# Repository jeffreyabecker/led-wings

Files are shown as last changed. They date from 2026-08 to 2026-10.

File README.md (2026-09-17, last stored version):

# Wings

One-off LED-lit wing costume — off-the-shelf SK9822 strips cut into per-feather chunks, data
daisy-chained chunk-to-chunk, power fed from buck-module power-hubs, driven by a Pixelblaze.

## Build strategy

- **Off-the-shelf electrical system** — no custom PCBs for this build. SK9822 96 LED/m strips
  cut to per-feather LED counts; Pixelblaze V3 controller; buck-module + fuse power-hubs.
- Custom boards (KiCad 10 + `pcbnew` parameterized feathers) are deferred to "if we build
  more than one".

## Boards

- [Boards](boards/README.md) — the build plan: strip-chunk cut table, covert rows, controller,
  power hubs, settled COTS parts. **Source of truth for the electrical build.**

## Feather templates

- [Templates](mechanical/templates/) — **physical feather templating only**: outlines + geometry,
  the generator, and shape sourcing. No electronics content — lighting lives in
  [boards/lighting-and-boards.md](boards/lighting-and-boards.md).

## Mechanical

- [Mechanical](mechanical/) — physical wing structure: [structural](mechanical/structural/) frame

## Shared docs

- [Connector pinout](docs/connector-pinout.md) — pigtail wiring legend (PWR / DATA-IN / DATA-OUT wire pairs + colors)

## Investigations

- [Battery](investigations/battery/) — 12 V chemistry + sizing for 8 h @ 20 % mobility
- [Connectors](investigations/connectors/) — board-to-wire family options for the strip ends
  (pitch-split power/data, JLCPCB-assembled)

## Repository layout

- `boards/` — **electrical build**: strategy, feather lighting map, wiring legend, settled
  parts. All electronics information lives here (or in `docs/`).
- `mechanical/templates/` — **physical feather templating only**: outlines, geometry, generator,
  shape sourcing. No electronics/lighting content — that belongs in `boards/`.
- `mechanical/` — wing structure (frame, backplate, harness mounts).
- `docs/` — shared electrical references (connector pinout, pigtail crimp guide).
- `investigations/` — one-off research (battery, connectors, diffuser halo).

## Changing the plan

Update [boards/README.md](boards/README.md) — it is the single source of truth for the
electrical build.

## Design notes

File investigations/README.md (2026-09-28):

# Investigations

Non-board design investigations — architecture, part-selection, and cost questions that
don't yet have their own board folder. Each investigation keeps a `README.md` (scope +
decision context) plus one or more analysis notes.

| Investigation | Status | Question |
|---|---|---|
| [Battery](battery/) | investigation | Which 12 V battery (chemistry + size) powers 8 h @ 20 % for mobility? |
| [Connectors](connectors/) | investigation | Which 2-pin board-to-wire family (pitch/keying) for strip ends, JLCPCB-assembled? |
| [Diffuser halo](diffuser-halo/) | investigation | How to make a thin, directional, resin-free diffuser bent into a halo ring? |
| [Side-facing LED placement](side-facing-led-placement/) | investigation | Where do edge-lit strips sit (distance/angle/density) for ≤ 7 mm feathers with an opaque foam top? |
| [Wing bones](wing-bones/) | target | Bone-structure layout + backplate → build plan: [structural/wing-structure-plan.md](../structural/wing-structure-plan.md) |

## Conventions

- Status: `investigation` (in progress) · `target` (decided direction) · `recommended` · `rejected` · `superseded`.
- Cite the source for every spec or price; mark estimates `⚠️` vs confirmed `✅`.
- A recommendation here is an *input* to the [boards doc](../boards/README.md), not a locked
  decision. Locking decisions still happens there.

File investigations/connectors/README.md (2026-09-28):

# Board-to-Wire Connector Selection — Research

> **Status: proposal** — no connector family chosen yet. This supersedes the earlier
> JST-PNI wire-to-wire plan. Scope: **2-pin board-to-wire connectors for the strip ends**,
> **JLCPCB/LCSC-assembled** (part must be in the JLCPCB assembly library or available
> through LCSC for consigned/PCBA sourcing).

## Constraints (from project + user)

| # | Requirement | Source |
|---|---|---|
| 1 | **Small footprint / pitch** — strip is **10 mm wide**, chunk ends are tight | `boards/lighting-and-boards.md` |
| 2 | **Keyed vs unkeyed, or male/female split, so power ≠ data** | user requirement |
| 3 | **Board side must be JLCPCB-assembled** (SMT placement) | user requirement |
| 4 | Wire side is hand-crimped (or pre-made cable) | build reality |
| 5 | Current: power run ≤ ~1.4 A per chunk @100 %; data negligible | `boards/hub-board.md` §6 |
| 6 | Two separate 2-pin pairs per chunk end: **power** and **data** | `docs/connector-pinout.md` (legacy) |
| 7 | Wearable — must not back out under flex/vibration | `` |

## Key insight: how to stop mixing connectors

There are **three** independent mechanisms, and you want to use **two at once**:

1. **Pitch difference (best, mechanically enforced).** Power on one pitch, data on another.
   A data plug physically cannot enter a power receptacle. Zero label reading, zero mistakes.
2. **Keying / polarisation.** Same pitch, different key. Cheaper (one tool, one crimp die)
   but relies on the moulded key being distinct enough to feel.
3. **Gender / colour / position.** Weakest — colour is invisible in a wing at night; gender
   only stops the wrong *pairing* if the two families differ.

**Recommendation: use mechanism 1 (split by pitch) as the primary, and mechanism 3
(harness position discipline) as the secondary.** Details in the recommendation section.

## Candidate families

All parts below are standard, widely-stocked families that appear in the LCSC/JLCPCB
ecosystem (either directly as the JST original or as the ubiquitous pin-compatible clone).
Verify the exact LCSC C-number and JLCPCB library status before committing — see
§Verification.

### A. 1.0 mm pitch — JST SH class

| | |
|---|---|
| Board header (SMT, side entry) | `SM02B-SRSS-TB` |
| Board header (SMT, top entry) | `BM02B-SRSS-TB` |
| Wire housing | `SHR-02V-S-B` |
| Contact | `SSH-003T-P0.2-H` |
| **Pitch** | **1.0 mm** |
| **Current rating** | **1 A AC/DC (AWG #28)** |
| Voltage | 50 V |
| Wire | AWG #32–#28 (0.032–0.081 mm²) |
| Lock | Friction lock (no positive latch) |
| Mounting height | ~2.9 mm (side entry) |

**Verdict:** the smallest credible option. **1 A rating is marginal** — a power run at
1.2 A is already over the JST number. Fine for **data**, tight for power.

### B. 1.25 mm pitch — JST GH class

| | |
|---|---|
| Board header (SMT, side entry) | `SM02B-GHS-TB` |
| Wire housing | `GHR-02V-S` |
| Contact | `SSHL-002T-P0.2` |
| **Pitch** | **1.25 mm** |
| **Current rating** | **1 A AC/DC (AWG #28)** |
| Voltage | 50 V |
| Wire | AWG #30–#26 |
| Lock | **Friction lock + housing lock (positive latch)** |
| Mounting height | ~1.25 mm (very low) |

**Verdict:** as low-profile as SH but with a **proper latch** — a real win for a wearable.
Still 1 A, and the GH contact needs a **different crimp die** than SH (smaller).
GH is a strong "low-profile" pick but shares the 1 A ceiling.

### C. 1.5 mm pitch — JST ZH class

| | |
|---|---|
| Board header (SMT, side entry) | `SM02B-ZHS-TB` |
| Board header (SMT, top entry) | `BM02B-ZHS-TB` |
| Wire housing | `ZHR-2` |
| Contact | `SZH-002T-P0.5` |
| **Pitch** | **1.5 mm** |
| **Current rating** | **1 A AC/DC (AWG #26)** |
| Voltage | 50 V |
| Wire | AWG #32–#26 |
| Lock | Friction lock |
| Mounting height | ~3.5 mm |

**Verdict:** you already have `C145992` (ZH 4-pin) pulled into the library, so the
footprint and crimp tooling are known. Wider than SH/GH but the widest wire range.

### D. 2.0 mm pitch — JST PH class (already in use for hub taps)

| | |
|---|---|
| Board header (SMT, side entry) | `S2B-PH-SM4-TB` (aka `PH2.0-2PWB`, LCSC `C47647`) |
| Wire housing | `PHR-2` |
| Contact | `SPH-002T-P0.5S` |
| **Pitch** | **2.0 mm** |
| **Current rating** | **2 A AC/DC (AWG #24)** |
| Voltage | 100 V |
| Wire | AWG #32–#24 |
| Lock | Friction lock (with optional locking variant) |

**Verdict:** **the only family here rated for the power you actually need.** Already
specced for the hub taps, so the tooling, footprint and crimp die exist in the build.

### E. 2.0 mm pitch, keyed — JST PA class

| | |
|---|---|
| Board header (SMT, side entry) | `BM02B-PASS-TFT` |
| Wire housing | `PAR-02V` |
| Contact | `SPA-001T-P0.5` (or `-P0.5S`) |
| **Pitch** | **2.0 mm** |
| **Current rating** | **3 A AC/DC (AWG #22)** |
| Voltage | 250 V |
| Wire | AWG #28–#22 |
| Lock | **Positive lock (inner), panel lock** |
| Keying | **Yes — housing is polarised/keyed** |

**Verdict:** highest current in this survey (3 A), a real latch, and genuinely keyed.
Cost: 2.0 mm pitch is the largest footprint, and it needs its **own crimp die** — a third
die in the toolbox next to PH and the small-pitch family.
**Note:** the wire-to-wire sibling is the **PNI family** you originally picked — PA is its
wire-to-board partner, so this is the natural evolution of that plan.

### F. 2.0 mm, board-in (no header) — JST SJN class

| | |
|---|---|
| Board-in, side entry | `02P-SJN` |
| Contact | `SJN-001PT-0.9` |
| **Pitch** | **2.0 mm** |
| **Current rating** | **3 A AC/DC (AWG #22)** |
| Voltage | 250 V |
| Mounting | **Through-hole, side entry, 2.8 mm mounting height** |

**Verdict:** interesting because the housing **sits on the board** and you solder the
contacts straight through — no SMT header, no mating halves. But it is **through-hole**
(so *not* plain SMT assembly) and it is a board-in style, which means the wire exits the
board plane. Worth noting, probably not the pick here.

### G. 1.25 mm, unkeyed + latching alternatives (Molex PicoBlade / clones)

| | |
|---|---|
| Board header (SMT) | `53398-0271` (PicoBlade 1.25 mm, vertical) |
| Wire housing | `51021-0200` |
| **Pitch** | **1.25 mm** |
| **Current rating** | **1 A** |
| Lock | Friction lock |
| Note | PicoBlade clones (`MX1.25`) are **very** well stocked at LCSC, cheapest option |

**Verdict:** cheapest and best-stocked at LCSC, but **unkeyed** and 1 A — it fails the
"don't mix connectors" goal on its own. Use only if price dominates.

## Comparison

| Family | Pitch | Rating | Wire | Lock | Keyed | SMT | Die needed |
|---|---|---|---|---|---|---|---|
| **SH** | 1.0 mm | 1 A | #32–28 | friction | ✗ | ✓ | SH/1.0 |
| **GH** | 1.25 mm | 1 A | #30–26 | **latch** | ✗ | ✓ | GH/1.25 |
| **ZH** | 1.5 mm | 1 A | #32–26 | friction | ✗ | ✓ | ZH/1.5 |
| **PH** | 2.0 mm | **2 A** | #32–24 | friction | ✗ | ✓ | PH/2.0 *(have)* |
| **PA** | 2.0 mm | **3 A** | #28–22 | **latch** | **✓** | ✓ | PA/2.0 |
| **SJN** | 2.0 mm | 3 A | #28–22 | — | — | ✗ (THT) | — |
| **PicoBlade** | 1.25 mm | 1 A | #28–26 | friction | ✗ | ✓ | 1.25 |

## Recommendation

**Split by pitch — two families, two roles. This satisfies "small footprint" and
"can't mix them" simultaneously, with no reliance on colour or keys.**

| Role | Family | Board part | Rating | Why |
|---|---|---|---|---|
| **POWER** (hub tap ↔ chunk) | **PH, 2.0 mm** | `S2B-PH-SM4-TB` (`C47647`) | 2 A | Already in the BOM, tooling and footprint on hand; only family that clears the current; 2.0 mm is *wide on purpose* so it can never enter a data socket |
| **DATA** (chunk ↔ chunk) | **SH, 1.0 mm** *(or GH if you want the latch)* | `SM02B-SRSS-TB` | 1 A | Tiny, well-stocked, and 1.0 mm physically cannot mate with 2.0 mm PH |

Why this shape:

- **Physically enforced.** A 1.0 mm SH plug cannot enter a 2.0 mm PH receptacle and vice
  versa. Power/data mix-ups become impossible rather than merely unlikely.
- **Current-correct.** Data carries no current (regenerated SPI, negligible); 1 A is
  ample. Power gets the 2 A PH it already needs.
- **One new family only.** You already use PH. This adds exactly one small-pitch family
  (SH), not three.
- **Footprint budget.** 10 mm strip width fits a 2.0 mm power header plus a 1.0 mm data
  header side by side with room to spare.

**If you would rather have a positive latch on every connector** (strongly advised for a
wearable that flexes), swap the two rows:

| Role | Family | Board part | Note |
|---|---|---|---|
| POWER | **PA, 2.0 mm keyed** | `BM02B-PASS-TFT` | 3 A + latch + keyed — best electrical/safety pick |
| DATA | **GH, 1.25 mm latched** | `SM02B-GHS-TB` | latch in a tiny package |

This costs a third crimp die (PA) but gives a latch on both halves and 3 A on power.

**Fallback if price dominates:** PH (power) + PicoBlade/MX1.25 clone (data). Cheapest and
best-stocked, but the data side is unkeyed 1 A — acceptable *only* because the pitch
split already prevents mis-mating.

## Verification checklist (do before committing)

The LCSC/JLCPCB catalogue pages are JS-rendered and could not be scraped, so confirm each
of these in the JLCPCB parts library by hand:

1. **JLCPCB library status** — search the JST MPN *and* the generic name
   (e.g. `SM02B-SRSS-TB`, `SH 1.0 2P`, `S2B-PH-SM4-TB`, `PH2.0-2PWB`). JLCPCB stocks both
   JST originals and pin-compatible clones; confirm which, and whether it is
   **"Preferred"/"Standard"/"Extended"**.
2. **Record the LCSC C-number** for: board header, wire housing, and contact — all three,
   for each family. A missing housing/contact breaks the wire side.
3. **Assembled part vs basic part** — Extended parts may carry a per-order setup fee.
4. **Minimum order / reel** — SMT headers are tape-and-reel; confirm MOQ vs the ~300
   board-side connectors this build needs.
5. **Crimp die** — confirm a die exists for each contact series. The `SN-28B` style
   ratchet does **not** fit JST small-pitch contacts; budget one die per family.
6. **Current derating** — "1 A (AWG #28)" is at #28. If power runs at 1.2–1.4 A, stay on
   PH/PA (2–3 A), not SH/GH (1 A).
7. **Strip-side anchor** — confirm the SMT header + epoxy strain relief still fits the
   10 mm strip end (`boards/2020-leds/`).

## Open questions

- Does the strip end have room for a **2.0 mm header plus a 1.0 mm header**, or does the
  power tap stay on the hub side only?
- Is a **positive latch** a hard requirement, or is friction lock acceptable given the
  feathers will be potted/strain-relieved anyway?
- Do you want a **locking PH variant** (`S2B-PH-SM4-TB(LF)(SN)` has a friction lock; the
  `SM4` locking-latch variants exist) to get a latch without adding PA?
- Does JLCPCB assembly cover the **strip FPC** at all, or are the strip boards hand-built?
  This changes whether the board-side part must be in the JLC library.

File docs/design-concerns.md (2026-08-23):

# LED Lighting PCB — Design Concerns

> Project: Addressable LED lighting PCBs
> LED part: [SK9822-EC20](https://www.lcsc.com/product-detail/C2909059.html) (LCSC `C2909059`)
> Connectors: JST-PH style (input / output / power injection)

## Part summary

- **SK9822-EC20** — 5V addressable RGB LED with built-in driver IC.
- **Package:** 2020 SMD (2.0 × 2.0 mm), ~0.2 W per device.
- **Protocol:** 4-wire — `VCC`, `GND`, `DATA`, `CLK` (APA102-compatible). Separate clock and
  data lines, each regenerated on the device's `DO`/`CO` outputs.
- **Current draw:** ~40 mA per LED at full-brightness white (R+G+B all on).

References:
- [LCSC product page](https://www.lcsc.com/product-detail/C2909059.html)
- [SK9822-EC20 datasheet (Normand LED)](http://www.normandled.com/upload/202003/SK9822-EC20%20LED%20Datasheet.pdf)
- [SK9822-EC20 overview](https://www.normandled.com/Product/view/id/840.html)

---

## 1. Power delivery — the #1 problem (5V is unforgiving)

- Each LED draws ~0.2 W at 5V → **~40 mA at full-brightness white**. A 100-LED string is
  **4 A** — cannot be pushed through one thin trace or one connector pin.
- **Voltage drop:** at 5 V there is almost no headroom. Even 0.5 V drop = 10%, which shows up
  as pink/wrong colors (blue channel dies first) and flicker at the far end of the string.
  This is why power injection is planned — but the injection interval must be **calculated**,
  not guessed.
- **Copper weight / trace width:** a 1 oz, 10 mm-wide trace drops ~60 mV per meter per amp.
  At 4 A over a strip this adds up fast. Use 2 oz copper or wide pours; treat the power path
  as a bus, not a signal trace.
- **Ground is a bus too.** Return current is the same 4 A. Starving ground shifts the
  clock/data reference.

## 2. JST-PH connector limits (the critical constraint)

- **JST-PH is rated ~2 A per circuit** (typically mated with 24–28 AWG wire). One VCC pin +
  one GND pin = **2 A max through the connector** — roughly 50 SK9822 LEDs at full white, less
  with margin.
- For larger strings: **add more 2-pin injection points** (each ≤2 A) rather than a bigger
  connector.
- **Pinout discipline:** pick one canonical pinout and use it everywhere. A mismatched
  daisy-chain connector is the classic way to blow a whole string.
- **Polarity/reversal protection:** JST-PH is not keyed against swapping power polarity. Add
  series Schottky or P-MOSFET reverse-polarity protection and/or a fuse, plus unambiguous
  silkscreen marking.

## 3. Signal integrity (data + clock)

- Separate `CLK` + `DATA`, regenerated on each device's `DO`/`CO` outputs → far more robust
  than 1-wire WS2812. Still:
  - **Series resistor (33–100 Ω)** on DATA and CLK — lives on the controller board (external),
    damping the controller→first-board cable.
  - Keep clock and data paired and reasonably matched; avoid large loop areas.
  - Expect **5 V logic** on data/clock. Level shifting from the controller is handled
    **externally** — not a board-level concern.
- Long runs: `CLK` is the double-clock risk. A pull-down/termination on the last board's `CO`
  can help on very long daisy chains.

## 4. Decoupling / bypass caps

- **Bulk cap (100–470 µF)** at each power-injection point to absorb inrush/transients.
- **100 nF ceramic near each LED or every few LEDs** (0.1 µF per device ideal; one per 1–4
  LEDs in practice).
- Caps also suppress constant-current driver switching noise that couples back onto data lines.

## 5. Thermal

- 0.2 W/device is small, but a dense board at full white is a real heat load; the 2020 package
  has little thermal mass.
- Use **copper pours** on VCC/GND as heat spreaders; avoid tiny thermal reliefs that choke heat.
- For sustained full-white, derate current or add spacing/airflow — lifetime and color stability
  drop fast with junction temperature.

## 6. Layout & manufacturability

- The 2020 package has **fine pads and a specific center/thermal pad** — follow the datasheet
  footprint exactly. Pick-and-place + reflow, not hand-solder friendly at density.
- **Mark data direction on silkscreen** (`DI` vs `DO`) — SK9822 is directional; every board in
  the chain must be oriented consistently.
- Keep high-current power path separate from signal path; return `DO`/`CO` cleanly to the next
  connector without crossing the power bus.

## 7. Protections & robustness

- **Fuse** (or polyfuse) — on the controller/distribution board (one per strand).
- **ESD/TVS** — on the controller board; segments rely on the SK9822's internal ESD protection.
- Reverse-polarity protection as noted in §2 (stays per board).

---

## TL;DR

The two things most likely to kill the project:

1. **Current capacity vs. the 2 A JST-PH limit.**
2. **5 V voltage drop over the string.**

Followed by signal integrity on `CLK`/`DATA` and bypassing. Everything else is refinement.

## Open items / next steps

- [ ] Calculate LEDs per injection point and per PH connector at target brightness (trace width,
      copper weight).
- [x] Define canonical connector pinout — see [connector-pinout.md](connector-pinout.md).
- [x] Input/output both 4-pin for off-the-shelf cables; direction marked by silkscreen — see [connector-pinout.md](connector-pinout.md).
- [x] Source connector part numbers (Boomele/JST-PH on LCSC) — see [selected-parts.md](selected-parts.md).
- [ ] Schematic symbol/footprint spec (connectors + SK9822-EC20).

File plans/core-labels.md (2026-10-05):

# Plan: label the geometry core

**Status:** proposed, not executed.
**Scope:** add `inkscape:label` attributes to the elements of
`templates/aggregate.svg` so the core is navigable in Inkscape's Objects and XML
panels. **No ids are renamed** — every existing `id` stays byte-identical, so the
sheets masters' `../aggregate.svg#<id>` hrefs keep resolving and nothing needs
rewriting.

Verified against the working tree after the reorg landed (`templates/aggregate.svg`,
769 lines, 129 elements, 134 ids, **0 duplicate ids**, **0 elements without an id**).
The reorg is mid-flight in the worktree: the two sheets documents and the core are
currently not well-formed XML, which is why the mechanics below are stated as
"by hand in Inkscape" rather than as a script step.

## 1. Why labels at all

Inkscape's Objects panel and the XML editor's element list show `inkscape:label`
when an element has one, and the raw `id` otherwise. The core's ids are either terse
by design (`P1-outline`) or Inkscape-generated noise (`path5-8`, `path13-2`,
`path55`-style dividers), so a maintainer opening the file today reads a list of
`path1 … path66` with no way to tell a divider from a wing profile. A label is the
only fix that does not rename anything, and renaming is exactly what we are avoiding
so the sheets masters keep working.

Labels are **maintainer metadata, not product data**: `inkscape:` is a
non-standard namespace, so the flattener strips every label on the way out. A
shipped CAM file must not carry them.

## 2. What gets a label

Counted from the current file, by class:

| count | element | role |
|---|---|---|
| 28 | `<path class="outline">` in a `<g class="feather">` | the catalog parts |
| 28 | `<path class="divider">` | the dividers between the feathers of one family |
| 8 | `<g class="align">` + 8 `<path class="outline">` inside them | the diagnostic overlays |
| 8 | `<path class="guide">` | the `*-topline` guides in `assembly-template` |
| 1 | `<path class="outline" id="path5-8">` in `<g id="full-outline">` | whole-wing profile |
| 1 | `<path class="outline" id="upper-outline">` in `<g id="assembly-template">` | upper cover of the assembly |
| 8 | `<g class="family …">` | the family groups |
| 6 | calibration `<line>`/`<text>` | the scale reference |
| 3 | misc `<g>` wrappers (`full-outline`, `align`, `assembly-template`, `calibration`) | containers |

That is ~91 elements. The eight `<g class="family …">` groups are worth doing
because the Objects panel nests by group, so the family is the first thing a
maintainer sees and the label is what names it.

## 3. Label text

One rule: **the label names the element in the maintainer's vocabulary, and repeats
the id only when the id is the identity a person would search for.** No id is ever
encoded into a label that does not already contain it.

| element | label | why |
|---|---|---|
| `<g class="feather" id="P1">` | `P1 right feather` | the id is the part identity |
| `<path class="outline" id="P1-outline">` | `P1 outline` | confirms which path in the group is the cut profile |
| `<g class="family p">` | `P family` | family letter + kind |
| `<path class="divider" id="path1">` | `P divider` | the generated id says nothing; the role does |
| `<g class="align" id="P-align">` | `P align overlay` | distinguishes the overlay from the family |
| `<path class="outline" id="path8-1">` | `P align outline` | the overlay's outer boundary |
| `<path class="guide" id="P-topline">` | `P topline guide` | assembly alignment line |
| `<path id="path5-8">` | `wing outline` | whole-wing profile; **needs your confirmation** |
| `<path id="upper-outline">` | `upper cover outline` | **needs your confirmation** |
| `<line id="calibration-centerline">` | `calibration centreline` | — |
| `<line id="calibratin-zero-line">` | `calibration zero line` | id keeps its typo; the label does not |
| `<line id="metric-50mm-line">` | `calibration 50 mm` | — |
| `<line id="us-2in-line">` | `calibration 2 in` | — |
| `<text id="metric-50mm-label">` | `50 mm text` | — |
| `<text id="us-2in-label">` | `2 in text` | — |

Two open questions in that table, both because I am inferring from id, path length
and parent transform rather than from knowing what the path draws:

- `path5-8`, the single path inside `<g id="full-outline">`, whose parent carries
  `translate(-1317.2834,-272.68523)`, and whose `d` is the longest in the file
  (~2300 chars). I read it as an exported whole-wing profile.
- `upper-outline`, the single `<path class="outline">` in `assembly-template`,
  sitting above eight `*-topline` guides. It is referenced nowhere else in the tree,
  so what it depicts is not recoverable from the file.

## 4. Label uniqueness

The flattener's manifest keys rows on a name, so labels must be unique even though
Inkscape does not enforce that. Two families of near-collision, both already avoided
by the table above:

- **The overlay vs. its family.** `<g id="P-align">` is `P align overlay`, and the
  family group `<g class="family p">` is `P family` — the letter alone would collide.
- **The overlay's outline vs. the part outline.** `P align outline` vs `P outline`.

Verification must therefore include a duplicate-label check (§6), not just a
coverage check.

## 5. Mechanics

Do it **by hand in Inkscape**, not by script:

1. Open `templates/aggregate.svg`. Saving from Inkscape repairs the current
   well-formedness breakage as a side effect, which a scripted edit cannot do (a
   script would have to parse the broken file first).
2. Select an element, open Object Properties (`Ctrl+Shift+O`), type the label. The
   Objects panel (`Ctrl+Shift+L`) shows the same labels and is the fastest way to
   walk a family and its dividers in order.
3. For the divider paths and the two unknown outlines, the canvas is the only
   reliable way to find them: their generated ids are unique, so `Edit → Find`
   (or the XML editor's element list) can select by id when the drawing position is
   ambiguous.
4. Save with Inkscape's default SVG 1.1 output.

No script, no `id` attribute is touched, and no other file changes. Git will show a
single-file diff of added label attributes (plus whatever Inkscape normalises on
save, which is why this should land as its own commit).

## 6. Verification

- Every element in §2 carries a non-empty `inkscape:label`: count labels against the
  element census (28 parts, 28 dividers, 8 align groups, 8 align outlines, 8 guides,
  8 families, 6 calibration, the two unknowns, the wrappers).
- **No duplicate labels** across the whole file.
- **No `id` changed**: `git diff` shows only added `inkscape:label` attributes on
  those lines, and the id set before and after is identical.
- `templates/feathers/sheets.svg` and `templates/alignment/sheets.svg` still resolve
  their `../aggregate.svg#<id>` hrefs — they were never edited, so this is a check
  that the "no renames" promise held, not a repair.
- Open the core in Inkscape's Objects panel: families nest, and every leaf reads as
  a name rather than `path42`.

## 7. Out of scope

- Renaming any id (deliberately deferred; it would break the two sheets masters).
- Labels in the shipped CAM output — the flattener removes the `inkscape:` namespace
  entirely.
- The current well-formedness breakage in the three SVGs, beyond Inkscape repairing
  the core on save. If the sheets masters are still malformed when this lands, that
  is a separate fix.
- A convention entry in `templates/AGENTS.md` recording "new core geometry gets a
  label, and label text follows §3" — worth adding, but it belongs with whatever
  edits that file next.

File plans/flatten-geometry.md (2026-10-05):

# Plan: flatten a work file into CAM geometry (`flatten_geometry.py`)

**Status:** proposed, not executed.
**Scope:** a new stdlib-only Python script that reads a *work file* — a document
that composes geometry out of a geometry core by `<use>`, orients it, and selects a
subset — and writes raw, flat, bed-ignorant geometry for CAM software to position
inside a machine. It does not change `tile_sheets.py`, `plans/templates-reorg.md`'s
print pipeline, or the geometry core's ids.

Settled in review (this is the design driver, not an inference):

- the input is a **new kind of document**, not the tiler's print output and not the
  geometry core: it carries `<use>` references into the core, plus rotation,
  reorientation and subset selection;
- the output is **ignorant of the CAM bed** — no tiling, no paper, no pages, no
  registration marks, no bed frame. The CAM software positions the work under the
  user's own target conditions, so the flattener's job is *simplify*, not *lay out*.

Consequence: `tile_sheets.py` is not in this pipeline at all. Tiling is a printing
concern (page-sized stock, overlap bands, join marks) and the bed is a CAM concern;
each is somebody else's stage. The flattener only resolves and simplifies.

## Decisions this plan encodes

| decision | choice |
|---|---|
| script name | `flatten_geometry.py` |
| input | a work file: `<content>-work.svg` (see §2 — the one naming question still open) |
| geometry core | referenced by the work file, never opened as the top-level input |
| output location | `templates/cam/` (as directed) |
| output names | `templates/cam/<work>-<subset>.svg`, one file per selected work |
| output frame | **no bed frame**; units declared as mm, origin owned by the work file |
| coordinate system | absolute millimetres, **every transform baked into path data** |
| shapes | `rect`/`circle`/`ellipse`/`line`/`polyline`/`polygon` → `<path>` |
| emitted geometry | centreline cut paths only; labels, bounds, guides, reg marks dropped |
| CSS | all styling stripped; geometry is `fill:none`, `stroke:none`; kerf offered as an optional non-authoritative attribute and in the manifest |
| manifest | `templates/cam/index.tsv`, one row per emitted path plus a census of what was dropped |

## 1. What the script is called

**`flatten_geometry.py`**, at the repo root beside `tile_sheets.py` (or in
`templates/` if `plans/templates-reorg.md` moves the tools there). `flatten` is the
SVG term for resolving `<use>` into copies; `geometry` names what survives — this is
not a general-purpose flattener, because labels, bounds, guides and marks are
losses it makes on purpose.

Rejected: `flatten_for_cam.py` (names the audience, not the transform),
`resolve_use.py` (describes only the first of the three things it does),
`flatten.py` (too generic beside `tile_sheets.py` / `inline_css.py`).

CLI, mirroring `tile_sheets.py`'s conventions (`USAGE` string, positional input,
explicit `--out`, `--whatif`, stdlib only, no argparse):

```
python flatten_geometry.py <content>-work.svg --out templates/cam/<work>-<subset>.svg
                            [--subset <group-id>]... [--all-subsets]
                            [--geometry <core.svg>] [--ref-dir <dir>]...
                            [--kerf] [--include-reference] [--include-marks]
                            [--keep-groups] [--check] [--whatif]
```

- `--subset` takes a group id inside the work file; repeatable. Without it, the whole
  work file is flattened as one work (the file's own selection stands).
- `--out` is required and is the file when exactly one work is emitted, the directory
  when several are (`--all-subsets`); the stem is derived per subset. Same rule as
  the tiler: no inferred output location, because a relative path written into a
  file is the failure mode this whole pipeline exists to delete.
- `--geometry` pre-seeds the core document so a work file copied away from its tree
  still resolves; `--ref-dir` adds search paths.
- `--check` re-flattens and compares against the committed output without writing.
- `--whatif` prints the resolved chain per path, the subset census, and the paths it
  would write.

## 2. What the input files are named

Two documents, two roles:

| role | name | contents |
|---|---|---|
| geometry core | `aggregate.svg` (reorg plan's name for today's `templates/feathers-elongated.svg`) | the 74 `<path>`s, ids `A1-outline` … `LC-All-outline`; 0 `<use>` |
| work file | `templates/<content>/<content>-work.svg` | `<use>` into the core, transforms, and the subset groups |

The work file is the composition layer: *this* content, rotated and reoriented like
this, using *these* parts. Today that role is played by
`templates/sheets-home-feathers.svg` and `templates/sheets-home-alignment.svg` —
43 and 18 `<use>` respectively, including the 14 self-referencing mirror clones
(`#sheet-P1-half` through `matrix(-1,0,0,1,210,0)`). Those files are exactly the
"new type of input" the brief describes; the plan's assumption is that they get the
`<content>-work.svg` name rather than a new sibling being invented beside them.

> **Open question, flagged not decided:** whether the work file *is* the existing
> sheets document renamed, or a third layer above it. Everything else in this plan is
> independent of the answer — the flattener takes one work file and a core, whatever
> they are called — but §3's output names are derived from the work file's stem, so
> the name has to be settled before the first run.

Naming grammar, so the pipeline reads out loud:

```
aggregate.svg             the geometry core (ids, no references)
<content>-work.svg        selection + orientation of core geometry
templates/cam/<stem>.svg  flattened, bed-ignorant output
```

No output name contains a `templates/` path, a paper token, a page number, or an
`id` from the core, so the whole tree can be renamed without touching the script.

## 3. What the output files are called

`templates/cam/`, as directed — below the tree that owns the sources, and outside
`targets/` because the CAM output is neither a print target nor paper-specific:

```
templates/cam/
  index.tsv                            manifest: every emitted path + the drop census
  README.md                            what regenerates this; nothing here is hand-edited
  feathers-work.svg                    whole work file, one work
  feathers-work-P1.svg                 --subset P1 (if subsets are emitted separately)
  alignment-work.svg
```

- The stem is the work file's stem, so source and output pair up by name
  (`feathers-work.svg` → `templates/cam/feathers-work.svg`).
- `--subset <group-id>` appends the subset token: one file per selected work, because
  a subset is a cutting job and mixing two jobs in one file is how the wrong profile
  gets cut.
- The **manifest** `templates/cam/index.tsv` is the thing that makes the tree
  auditable (tab-separated, one row per emitted path):

  | column | meaning |
  |---|---|
  | `work`, `subset`, `group` | source work file stem, subset id, the `id` of the group holding the path |
  | `role` | `cut` · `reference` · `mark` |
  | `path_id` | the emitted path's id |
  | `min_x`,`min_y`,`max_x`,`max_y` | tight bounds, mm, in output coordinates |
  | `kerf_mm` | the source stroke width, when `--kerf`; empty otherwise |
  | `src` | the resolution chain: `feathers-work.svg#P1R-use → aggregate.svg#P1-outline` |
  | `dup_of` | first entry that emitted identical geometry (mirror / duplicate detection) |

- `index.tsv` also carries a **drop census**: every dropped class with its count
  (`.label`, `.title`, `.note`, `.sheet-bounds`, `.reg*`, `.crop`, `.overlap`,
  `.guide`, `.divider`, `.cal*`, `.align`) and every subset that produced zero cut
  paths **with the reason**. In this tree that matters immediately: the cover and
  every `sheet-Alignment-*` group is layout and guide geometry, not parts, so those
  subsets are legitimately empty and must say so rather than look like a bug.

## 4. How the geometry is placed and organized

A work file is a cutting job, so the output is one document = one job, with no
notion of a bed, page, paper or machine:

1. **No frame is invented.** The flattener must not emit a `viewBox` sized to a
   sheet, a page or a bed — that is the bed coupling the brief rejects, and it would
   smuggle a placement decision into a file whose whole point is that placement is
   the CAM software's job. To make units unambiguous the root declares
   `viewBox="0 0 W H"` spanning the emitted geometry's tight bounds and
   `width="Wmm" height="Hmm"`, i.e. 1 user unit = 1 mm *by construction* — the frame
   is derived from the geometry, never the geometry fitted to a frame.
2. **No transforms survive.** The work file's rotations (e.g. `rotate(-4.0415212,
   -2276.4602,237.48561)` on `P1R-use`) and the mirror's `matrix(-1,0,0,1,210,0)`,
   the enclosing `translate` on `#sheets`, and the core's own
   `translate(-1317.2834,-272.68523)` on `full-outline` are all multiplied into path
   coordinates. Geometry gets `transform=None`, so an importer that ignored
   `transform` entirely would still be correct. `--keep-groups` preserves nesting
   with its transforms for eyeballing only.
3. **Path conversion.** `rect`, `circle`, `ellipse`, `line`, `polyline`, `polygon`
   become `<path>` (circles as two 180° arcs, `rx`/`ry` as corner arcs). No `<use>`,
   `<symbol>`, `<defs>`, `<clipPath>`, `<text>`, `<image>`, `style=`, or `class=`
   remains — the output has no dependency any consumer could drop.
4. **Groups keyed on source identity, never on position.** One `<g>` per subset and
   one per part, children in work-file document order:

   ```xml
   <g id="work" data-work="feathers-work" data-units="mm">
     <g id="subset-P1" data-subset="P1">
       <g id="part-P1R" data-part="P1" data-side="right" data-role="cut">
         <path id="P1-outline"
               d="…"
               data-src="feathers-work.svg#P1R-use → aggregate.svg#P1-outline"/>
       </g>
       <g id="part-P1L" data-part="P1" data-side="left" data-role="cut" data-mirror="of:part-P1R">
         <path id="P1-outline-mirror" d="…"/>
       </g>
     </g>
   </g>
   ```

   Ids come from the resolution chain (`part-P1R`, `P1-outline-mirror`), not from an
   array index, so adding a part does not renumber the others — the masters already
   name their groups this way (`sheet-P1-half`, `sheet-P1-labels`). The mirror stays
   explicit: it is a real geometric distinction (a flipped part is not a duplicate),
   and CAM needs to know a path is the reflected copy.
5. **What is kept by default** — the subset that represents material to be cut:

   | source class | emitted as | default |
   |---|---|---|
   | `.outline` inside a `class="feather"` group | `data-role="cut"` | **kept** |
   | `.outline` inside `.align` (the `*-align` / `A-align` overlay) | `data-role="reference"` | dropped (`--include-reference`) |
   | `.guide`, `.divider`, `.arrow` | `data-role="reference"` | dropped (`--include-reference`) |
   | `.reg`, `.reg-hole`, `.reg-axis`, `.reg-key` | `data-role="registration"` | dropped (`--include-marks`; these are print/assembly registration, not bed registration) |
   | `.cal`, `.minor`, `.major`, `.num`, `.caltext` | `data-role="mark"` | dropped (`--include-marks`) |
   | `.label`, `.title`, `.note` (`<text>`) | never emitted | dropped always — a cutter cannot cut text |
   | `.sheet-bounds`, background rects, `.crop`, `.overlap` | never emitted | dropped always |

   The drops are the "simplify for CAM" half of the brief: the operator wants cut
   profiles, and every other element is a printing or proofing aid. The `--include-*`
   flags exist so the same resolver can emit a reference or alignment program
   without a second tool.
6. **Ordering is the work file's, and it is preserved.** Nesting order, sibling
   order and each rotation land in the output exactly as the work file composed
   them; the flattener never sorts, optimises, or re-nests. If the work file says
   "P1 is rotated 4° anti-clockwise to fit the stock," that rotation is baked and the
   output records it in `data-src`, so the CAM operator inherits the decision instead
   of being asked to reproduce it.

## 5. What CSS is emitted

**None.** No `<style>` element, no `class` attribute, no presentation attribute on
the document — the CAM consumer's CSS support is unknown and unknowable, and a
stylesheet that *is* honoured produces a different file from the one that is not.
Styling is not geometry, so nothing about the geometry's *position* depends on it:

1. **Geometry carries only geometry.** Every emitted shape gets `fill="none"` and
   `stroke="none"` so no downstream default (a viewer's black fill, a CAM import's
   fill-to-path) can turn a cut profile into a filled region. No `stroke-width`,
   `stroke-dasharray`, `opacity`, colour or `font-*` survives — the source's
   `.outline { stroke-dasharray: 2.5, 2.5 }` (present in every master today) and the
   `.overlap { stroke-dasharray: 2 2 }` rule both disappear with the stylesheet, which
   removes by construction the class of bug the reorg plan calls out as live dashed
   cut paths.
2. **Kerf is data, not style, and it is opt-in.** `--kerf` adds
   `data-kerf-mm="0.5"` (the stroke width the source cascade resolved to) to each cut
   path and fills the manifest's `kerf_mm` column. It is deliberately *not* a
   `stroke-width`: a CAM file must not let a renderer's stroke be mistaken for a
   toolpath offset, and cutter compensation is the CAM software's decision. With the
   flag off, the manifest still records the resolved value, so a wrong kerf is visible
   before cutting without putting it in the geometry.
3. **Widths are millimetres and stated once.** The unitless source widths are only
   meaningful against an mm viewBox; §4.1 makes that true by construction and the
   manifest restates it, so `0.5` cannot be silently read as 0.5 px.
4. **Provenance is a comment, not styling** (same shape as the tiler's stamp):

   ```
   <!-- flattened by flatten_geometry.py: work=<path> sha256=<8> core=<path> sha256=<8>
        subsets=1 cut_paths=28 mirrors=14 dropped=labels:56,bounds:15,reg:105,guide:8
        css=none kerf=0.5 -->
   ```

   The source hashes are what make a flattened file traceable to the exact revision
   that produced it — the property the `<use>` documents get for free by pointing at
   their sources, and the reason a stripped file needs a stamp.

## 6. Verification

- No `<use>`, `<symbol>`, `<defs>`, `<clipPath>`, `<text>`, `transform=`, `url(#…)`,
  `href=`, `class=`, `style=`, `<style>` or `stroke-width` survives in any
  `templates/cam/*.svg`. Grep the emitted tree: this is the check that catches the
  no-op-that-looks-like-success failure mode, so it is a hard gate.
- Feathers work file: 28 distinct cut profiles per the catalog (14 parts × right/left),
  the 14 mirrored paths are reflections about their part's axis and are paired in the
  manifest by `dup_of`, and no two entries share identical `d` unless genuinely
  congruent parts do.
- Bounds: every emitted path's bounds lie inside the root `viewBox`, and the viewBox
  is the tight union of them.
- `index.tsv` lists the cover and every `Alignment-*` subset with `cut_paths=0` and a
  reason, and the drop census counts match the source (`labels:56`, `bounds:15`,
  `reg:105` for the current feathers sheets — measured, see the working tree).
- Render one flattened output at 1 mm/unit and overlay the source's equivalent region
  (Inkscape CLI `--export-type=png`, `--export-dpi`): the cut ink is congruent. A
  mismatch means a transform was multiplied in the wrong order (outermost first).
- A hand-edit to a baked `d` is reported by `--check` (try it once, revert).
- Re-flattening unchanged inputs is byte-identical, which is what lets the tree be
  regenerated on every master edit.

## 7. Risks and notes

- **The input name is the open decision** (§2). Everything else here is independent
  of it, but `templates/cam/` output stems derive from the work file's stem.
- **`templates/` is moving.** `plans/templates-reorg.md` renames the core to
  `aggregate.svg` and relocates every document. The naming grammar above is chosen to
  survive it: no output name encodes a `templates/` path, a paper token, or a sheet
  id.
- **The core is referenced by id, so a core rename breaks the work files**, not the
  flattener. The flattener fails loudly on an unresolvable href, naming the href and
  the file it looked in — the deep-relative-path silent failure is the known incident
  this repo keeps re-learning.
- **Nothing about cutting offsets.** With `stroke="none"` and no width, the output is
  centrelines; a CAM post that needs an offset outline does it downstream. That is
  the intended division of labour, and the reason `--kerf` is advisory.
- **Commit the output tree**, like `templates/targets/` per the reorg plan, so an
  operator can check out the repo and get the exact geometry that was cut.

## 8. Out of scope

- Tiling, pagination, overlap bands, join marks, paper sizes, registration marks —
  the printing pipeline's job (`tile_sheets.py`), and explicitly not the flattener's.
- Bed fitting, nesting, work offsets and toolpath ordering — the CAM software's job,
  which is the point of a bed-ignorant output.
- Stroke-to-path / offset outlines, DXF, HPGL, G-code, and any machine post.
- Any change to the geometry core's ids or the work files' geometry.

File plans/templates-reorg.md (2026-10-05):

# Plan: reorganize `templates/`

**Status:** tiler prerequisite **done**; the reorg itself is proposed, not executed.

- The `tile_sheets.py` behaviour changes that the re-tile depends on have landed (commit
  `e568aed`) and are recorded under [Tiler state](#tiler-state-landed) below, which is the
  residual of the former `plans/tile-sheets-changes.md`. Nothing else from that plan remains.
- What is left is everything below: the directory structure, file renames, reference rewrites, the
  CSS consolidation (one source per audience, generated into every document), and the folder docs
  that make the layout self-explanatory. No geometry or content changes.

Facts below were re-verified against the working tree at the time of writing.

## Decisions this plan encodes

| decision | choice |
|---|---|
| sheet masters vs targets | masters are target-agnostic, so they live **above** `targets/` |
| layout shape | `templates/<content>/sheets.svg` + `templates/targets/<target>/<content>/print-<paper>.svg` |
| print document references | keep thin `<use>` references (no inlining), accepting parent-directory hrefs |
| stylesheet | one source per audience under `templates/css/`, **generated into every SVG** at build time; nothing referenced at runtime |
| paper naming | `print-letter.svg`, `print-a4.svg` — the `--paper` token, so flag value and filename agree |
| `aggregate.svg` | the geometry master that sheets reference by id (today's `feathers-elongated.svg`) |
| PDFs | rendered from the print documents, parked at the target level |

## Tiler state (landed)

`tile_sheets.py` at the repo root already speaks the grammar this plan assumes, so the re-tile in
[step 4](#steps) needs no code change. Verified against the current masters:

| behaviour | state |
|---|---|
| sheet reference | relative to the output directory (`os.path.relpath` + `os.sep` → `/`), via `rel_href()` |
| output | `--out` required and its directory created; `--whatif` reports path, resolved href and output size |
| `sodipodi:docname` | the real output basename (`doc_name=os.path.basename(out_path)`) |
| provenance | one XML comment before `<svg>`: `tiled by tile_sheets.py: source=… paper=… trim=… safe=… overlap=… gap=… pages=… orientation=per-sheet` |
| shared defs | rendered by `emit_multipage_svg(shared_defs=…)`; no post-hoc `replace()` of the `<defs>` marker, so the silent no-op is gone |
| stylesheet | carried over from the master and gated: `require_style_rules()` fails unless the carried CSS plus `JOIN_CSS` defines `.join-line`, `.join-bar`, `.overlap`, `.note`. The old unconditional `CSS2` append is gone |
| CLI | `--paper <name>` required (or `--size WxH`), `--margin`/`--safe`, `--overlap`/`--gap`, `--list-papers`; sheet discovery is a class **token** test, so `sheet-bounds` and friends cannot match |

Measured with the current masters (letter, default overlap 12 / gap 10):

```
templates/sheets-home-feathers.svg    -> 28 pages from 15 sheets (13 tiled, 2 single-page)
templates/sheets-home-alignment.svg   -> 19 pages from 12 sheets (7 tiled, 5 single-page)
```

Both documents were regenerated and inspected: page counts 28 / 19, `class="…"` usage limited to
`join-line`, `join-bar`, `overlap`, `note`, two hoisted clip defs (`clip`, `clip-shared-2`), and a
provenance comment matching the parameters. These are the reference numbers for the post-reorg
re-tile; the regenerated files were not kept (see [step 4](#steps)).

## Target layout

```
templates/
  README.md                       naming grammar, pipeline, regeneration commands
  AGENTS.md                       folder rules (masters vs generated, machining model, registration)
  aggregate.svg                   geometry master, id-referenced by <use>
  css/
    geometry.css                  part, guide and mark presentation
    sheets.css                    sheet, label and registration presentation
  inline_css.py                   writes each master's <style> from css/; --check reports drift
  tile_sheets.py                  the tiler (moved here as drawn)
  feathers/
    sheets.svg                    sheet layouts, mm, registration + mirror pattern
    AGENTS.md
  alignment/
    sheets.svg
    AGENTS.md
  targets/
    AGENTS.md                     everything below here is generated
    home/                         US/ISO home-printer paper
      AGENTS.md                   canonical commands + parameter sets per paper
      feathers/
        print-letter.svg
        print-a4.svg
      alignment/
        print-letter.svg
      feathers-letter.pdf
      alignment-letter.pdf
```

The `multipage` moniker is retired: the stage word is `print`, and the only thing that varies in
the name is the paper.

## File mapping

| now | after | notes |
|---|---|---|
| `templates/feathers-elongated.svg` | `templates/aggregate.svg` | geometry master, 250×700 mm, own stylesheet, 0 `<use>` |
| `templates/sheets-home-feathers.svg` | `templates/feathers/sheets.svg` | 15 sheets; 29 external hrefs + 14 internal mirror `<use>` |
| `templates/sheets-home-alignment.svg` | `templates/alignment/sheets.svg` | 12 sheets; 18 external hrefs |
| `templates/sheets-home-feathers-multipage.svg` | `templates/targets/home/feathers/print-letter.svg` | 28 pages; 28 external refs — **regenerate**, the file was deleted in `e568aed` |
| `templates/sheets-home-alignment-multipage.svg` | `templates/targets/home/alignment/print-letter.svg` | 19 pages; 19 external refs — **regenerate** |
| — | `templates/targets/home/feathers/print-a4.svg` | new output, same master, A4 paper |
| — | `templates/targets/home/feathers-letter.pdf` | render of `feathers/print-letter.svg` |
| — | `templates/targets/home/alignment-letter.pdf` | render of `alignment/print-letter.svg` |
| — | `templates/css/geometry.css`, `templates/css/sheets.css` | new: the stylesheet sources |
| — | `templates/inline_css.py` | new: generates each master's `<style>` from `css/` |
| `tile_sheets.py` (repo root) | `templates/tile_sheets.py` | move only; behaviour work has landed |
| `templates/print/` | *deleted* | empty directory, absorbed by `targets/` |
| `templates/sheets-home-print.pdf` | *deleted* | orphan: its source SVG was removed at the split |
| `templates/feathers-letter-landscape.pdf` | *deleted* | orphan: `feathers-aggregate.svg` no longer exists |

The two multipage SVGs are the one place this plan differs from a pure rename: they were deleted in
the "cleaning up svgs and tiling" commit and are untracked-generated now, so there is no history to
carry. Generate them at their new paths and let the first commit record them as additions.

## Reference rewrites

Only two kinds, both mechanical:

1. **Masters → geometry master.** Every external `<use>` in both `sheets.svg` files changes
   `feathers-elongated.svg#<id>` to `../aggregate.svg#<id>`:
   - `feathers/sheets.svg`: 29 occurrences (28 outline symbols + `calibration`)
   - `alignment/sheets.svg`: 18 occurrences (8 `*-align` symbols + `assembly-template`)
2. **Print documents → masters.** Regenerated, never hand-edited. The tiler emits
   `../../../feathers/sheets.svg#sheet-P1` (three levels: `feathers` → `home` → `targets` →
   `templates`). 28 references for feathers, 19 for alignment.

Untouched by any of this: all element ids, sheet ids, `inkscape:current-layer`, `data-sort-order`,
the registration geometry, and the mirror `<use href="#sheet-*-half">` references. The `<style>`
bodies are rewritten, but their rules keep their meaning apart from the fixes listed below.

## CSS consolidation

The presentation exists in three hand-maintained copies that have already drifted — `aggregate.svg`
1,549 chars / 19 rule blocks, `feathers/sheets.svg` 2,836 / 39, `alignment/sheets.svg` 2,668 / 35.
The tiler no longer adds a fourth: it carries the master's stylesheet over unchanged and only adds
the two rules for its own join marks (`JOIN_CSS`).

**Shape:** one source per audience, generated into every document at build time. Nothing is
referenced at runtime.

| source | contents | generated into |
|---|---|---|
| `css/geometry.css` | `.outline`, `.guide`, `.arrow`, `.divider`, `.mark`, family fills | `aggregate.svg`, both `sheets.svg` |
| `css/sheets.css` | `.label`, `.title`, `.note`, `.sheet-bounds`, `.crop`, `.overlap`, `.reg*` | both `sheets.svg` |

Each document therefore carries the rules it needs for its own rendering, so a `sheets.svg` styles
its own clones of `aggregate.svg` geometry without depending on the geometry master being reachable
*as a stylesheet*.

- **Generator**: `templates/inline_css.py` rewrites each master's `<style>` body from the sources;
  `--check` fails when a document's rules no longer match the source. Compare rules
  (selector → declarations, order-insensitive), not bytes: Inkscape normalises CSS syntax when it
  re-saves a file, so a byte comparison would report drift that isn't.
- **Which source each document gets**: `aggregate.svg` gets `geometry.css` only — it renders
  geometry, not sheets — and both `sheets.svg` files get `geometry.css` + `sheets.css`. A
  `sheets.svg` must keep the geometry rules because it clones `aggregate.svg` content, and the
  tiler carries that same style text into every print document.
- **Why inline instead of `@import`**: a stylesheet reference is a runtime dependency with a silent
  failure mode. Any consumer that is not Inkscape — a CAM tool, a browser, a PDF flattener — may drop
  it, and cut paths would quietly lose their stroke. Inlining keeps every document self-contained.
- **Measured rather than assumed** (Inkscape 1.4, the version the files declare; probes left in
  `.tmp/css-probe/`): inline `<style>` works; `@import url(…)` inside `<style>` works; the
  `<?xml-stylesheet?>` processing instruction is ignored; and a referenced document's `<style>` *does*
  style the cloned content, scoped to the clone and propagating through two external hops. The old
  comment in `tile_sheets.py` ("CSS does not cascade across an external `<use>` reference") is not
  true on 1.4 — the stylesheet is still inlined here, but for consumer independence, not because
  cross-document styling fails.
- **Rejected**: deleting the geometry block from the sheets masters and leaning on `aggregate.svg`'s
  stylesheet reaching the clones. It works in Inkscape per the probe, but it makes appearance depend
  on cross-document behaviour that other consumers need not honour — and there is nothing left to save
  once the rules are generated rather than forked.
- **Defects fixed in the sources, so every document inherits the fix**:
  - `.outline`'s `stroke-dasharray: 2.5, 2.5` is never reset — dashed *cut paths*, currently live in
    all three files. Remove it, or reset it in the later `.outline` rule.
  - `.outline` is defined more than once per file; collapse to one definition per source.
  - family fills lost their `.highlighted` scoping when the style was forked from the master into the
    sheets; restore the scope, or drop it deliberately.
- **The ragged middle is expected, and `.crop` is the one casualty.** Generated print documents use
  exactly `join-line`, `join-bar`, `overlap` and `note` (`class="…"` values in both regenerated
  documents); the tiler draws no crop ticks, so its style gate (`require_style_rules`) deliberately
  does not require `.crop`. `.crop` belongs in `sheets.css` because both sheets masters style their
  own crop furniture with it — it simply stops mattering downstream. Do not "fix" that by having the
  tiler demand every class the masters define; the gate is about what a *page* renders.

## Folder docs to add

- **`templates/README.md`** — the naming grammar, the pipeline (`aggregate.svg` → `<content>/sheets.svg`
  → `targets/<target>/<content>/print-<paper>.svg` → `<content>-<paper>.pdf`), which files are
  hand-edited vs generated, the CSS pipeline (edit `css/`, run `inline_css.py`), and the regeneration
  commands.
- **`templates/AGENTS.md`** — masters vs generated; the machining model (one pattern per sheet, the
  left half is the mirrored back of the right, no drawn left geometry and no second program); the
  mirror `<use>` and why labels are baked rather than cloned; registration conventions (axis along
  sheet Y at the bounds-rect centre, Ø6 through-holes, on-axis hole plus ±20 mm twin pair, top-left
  key, all marks inside the bounds rect); id conventions (`{Group}{N}{L|R}`, `sheet-<name>-*`);
  the `<style>` bodies are **generated from `templates/css/`** — edit the source and run
  `inline_css.py`, never hand-edit a `<style>`, and keep the presentation inline because a `@import`
  is a runtime dependency other consumers may drop (`<?xml-stylesheet?>` is ignored by Inkscape
  outright); cut paths must never be dashed; any master edit invalidates its print documents.
- **`templates/feathers/AGENTS.md`** — author only inside `sheet-*-half`; never add left geometry by
  hand; labels live in `sheet-<name>-labels`; sheet ids are referenced by the print documents, so
  renaming one means re-tiling.
- **`templates/alignment/AGENTS.md`** — the same, minus the mirror pattern, noting the alignment
  sheets are single-sided today.
- **`templates/targets/AGENTS.md`** — generated output: never hand-edit, regenerate instead; keep
  committing the generated documents.
- **`templates/targets/home/AGENTS.md`** — what `home` means and the exact per-paper commands, spelled
  so they can be checked against a shipped file's provenance comment.

## Steps

1. **Create directories and move what exists** (`git mv`, so history follows):
   ```
   git mv tile_sheets.py templates/tile_sheets.py
   git mv templates/feathers-elongated.svg templates/aggregate.svg
   mkdir templates/feathers templates/alignment templates/css templates/targets/home/feathers templates/targets/home/alignment
   git mv templates/sheets-home-feathers.svg templates/feathers/sheets.svg
   git mv templates/sheets-home-alignment.svg templates/alignment/sheets.svg
   ```
   The print documents are not moved — they no longer exist (see [step 4](#steps)).
2. **Rewrite the masters' external hrefs**: `feathers-elongated.svg#` → `../aggregate.svg#`
   (29 + 18 occurrences). Verify the counts before and after; nothing else in those files changes.
   Apply the same rewrite to the two `sodipodi:docname` values that still name the old files
   (`sheets-home-print.svg` in the alignment master, its own old name in the feathers master).
3. **Extract and generate the CSS.** Create `css/geometry.css` and `css/sheets.css` from the existing
   stylesheets (fixing the three defects above), add `inline_css.py`, run it over all three masters,
   and confirm `--check` is clean. This has to precede the re-tile so the generated print documents
   pick up the regenerated styles.
4. **Re-tile** the print documents at their new paths, then add the A4 variant:
   ```
   python templates/tile_sheets.py templates/feathers/sheets.svg --paper letter --out templates/targets/home/feathers/print-letter.svg
   python templates/tile_sheets.py templates/alignment/sheets.svg --paper letter --out templates/targets/home/alignment/print-letter.svg
   python templates/tile_sheets.py templates/feathers/sheets.svg --paper a4 --out templates/targets/home/feathers/print-a4.svg
   ```
   Expect 28 / 19 pages for the letter documents, and the same counts from `--whatif` before and
   after the reorg. Two scratch runs of the pre-reorg masters already produced 28 / 19 pages and
   were inspected (see [Tiler state](#tiler-state-landed)); they were deleted again rather than
   committed, so this step is what puts the documents back in the tree.
5. **Render the PDFs** from the print documents (Inkscape CLI at
   `C:\Program Files\Inkscape\bin\inkscape.com`, `--export-type=pdf`), writing them at the target level.
6. **Delete the orphans and the empty directory**: `templates/print/`,
   `templates/sheets-home-print.pdf`, `templates/feathers-letter-landscape.pdf` (the last two are
   already deleted in the working tree; stage them).
7. **Write `README.md` and the five `AGENTS.md` files** (outline above).
8. **Verify** (see below), then commit.

## Verification

- No file under `templates/` still contains `sheets-home` or `multipage` (grep the whole tree,
  including the generated documents).
- From `templates/feathers/`, `../aggregate.svg` resolves; from `templates/targets/home/feathers/`,
  `../../../feathers/sheets.svg` resolves. The earlier missing-sibling incident is the reason this
  check is explicit.
- `python templates/inline_css.py --check` is clean for all three masters, and a hand-edit to a
  `<style>` body is reported as drift (try it once, then revert).
- Outlines render **solid**: no `stroke-dasharray` survives in any stylesheet, and a rendered sheet
  shows continuous strokes — this is cut-path correctness, not cosmetics.
- Print documents carry each shared rule once (no duplicate `.overlap` / `.note`), and their
  `class="…"` values are a subset of `join-line`, `join-bar`, `overlap`, `note`.
- Shared defs: one `<clipPath>` per distinct page geometry (letter gives two: `clip`,
  `clip-shared-2`), no repeated id anywhere in the document.
- The provenance comment in each print document matches the command in
  `templates/targets/home/AGENTS.md` — paper token, trim, safe, overlap, gap, page count.
- The sheet href in a generated page is `../../../feathers/sheets.svg#sheet-P1` and resolves from
  `templates/targets/home/feathers/`.
- `python templates/tile_sheets.py … --whatif` matches the committed page counts before and after:
  **28** for feathers, **19** for alignment at `--paper letter`.
- Open both print documents (Inkscape): page counts 28 and 19, and the referenced sheet content
  renders — not a blank page and not dashes-only.
- `git status` shows the moves as renames, so the content diffs are the href rewrites and the
  regenerated `<style>` bodies.

## Rollback

Everything is a `git mv` plus the href rewrite in two files and regenerated `<style>` bodies; reverting
the commit restores the previous layout. The generated documents can be re-tiled from either layout,
and the CSS sources are additive until the old copies are deleted.

## Risks and notes

- **Parent-directory hrefs**: a print document copied away from the tree no longer renders. The PDFs
  are self-contained, so printing does not depend on the tree.
- **Deep relative paths**: `../../../<content>/sheets.svg` is valid and Inkscape resolves it, but it
  is one more silent failure mode. Keep `targets/` inside `templates/` rather than moving it to the
  repo root.
- **Generated `<style>` bodies fight hand edits**: the moment someone tweaks a rule in Inkscape,
  `--check` will flag it. That is the point, but it needs to be stated in `templates/AGENTS.md` so it
  reads as intended rather than as noise.
- **Inkscape rewrites CSS syntax on save** (spacing, `2.5, 2.5` → `2.5,2.5`). Compare rules, not
  bytes, or every save looks like drift.
- **The feathers master's root page is currently 10 mm × 10 mm** (`viewBox="-495.664 751.564 10 10"`).
  Unrelated to this plan and harmless to the tiler (which reads the sheet bounds rects), but
  whole-document PDF/PNG exports of that file will be a 10 mm square. Worth fixing while the file is
  open.
- **A4 parameter set** (210×297 trim, 200×287 safe, overlap 12, gap 10) is an assumption; confirm it.
- **Proof of the re-tile is what grounds this plan**: the 28 / 19 page figures and the generated-file
  facts above came from running the landed tiler over the *current* masters. Re-run
  `--whatif` after the moves and compare, rather than trusting the numbers as copied.
- **Naming**: `emit_multipage_svg` and a few comments still say "multipage". That is the retired
  moniker; renaming the function is optional cleanup, not part of the reorg.

## Out of scope

- Runtime `@import` externalisation of the stylesheet — decided against in favour of generated inline
  styles (see "CSS consolidation").
- Any change to the sheet geometry, registration or mirror pattern.
- Inlining sheet content instead of `<use>` (decided against: print documents stay thin references).
- Page-orientation policy, overlap/gap defaults, and paper sizes beyond the tiler's table.
- Any change to what the sheets documents contain — the tiler reads them, it does not author them.
- A commit policy for generated files: recommendation is to keep committing them, and say so in
  `templates/targets/AGENTS.md`.

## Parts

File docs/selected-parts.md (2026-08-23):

# Selected Parts — Master BOM

> Single source of truth. Brief on purpose — rationale in [design-concerns.md](design-concerns.md),
> pinout in [connector-pinout.md](connector-pinout.md).
>
> Status: ✅ selected · ⚠️ to confirm · ⬜ TBD

## LED

| Ref | Part | Mfr | MPN | LCSC | Qty | Status |
|-----|---|-----|-----|---|-----|---|
| `LED*` | SK9822 addressable RGB, 5 V, 2020 | OPSCO | `SK9822-EC20` | [C2909059](https://www.lcsc.com/product-detail/C2909059.html) | TBD | ✅ |

## Board headers (SMD, side-entry — parallel to board, flex-compatible)

| Ref | Port | Color | Mfr | MPN | LCSC | Qty | Status |
|-----|---|---|-----|-----|---|-----|---|
| `J_IN` | input, 4-pin | white | JST | `S4B-PH-SM4-TB` | [C265102](https://www.lcsc.com/product-detail/C265102.html) | 1 | ✅ |
| `J_OUT` | output, 4-pin | distinct (≠ white) | hanxia | `HX PH2.0-4PWT` | [C22461287](https://www.lcsc.com/product-detail/C22461287.html) | 1 | ✅ |
| `J_PWR` | power, 2-pin | white | JST | `S2B-PH-SM4-TB` | [C295747](https://www.lcsc.com/product-detail/C295747.html) | 1+ | ✅ |
| (alt) | 4-pin white | white | Boomele | `2.0-4P卧贴` | [C53041](https://www.lcsc.com/product-detail/C53041.html) | — | ✅ |

> Side-entry SMD so the cable exits **parallel** to the board (flex PCB: no through-hole).
> `J_OUT` uses a distinct (non-white) color so it stays visually separate from the white input.

## Cables (off-the-shelf)

| Use | Cable | Source |
|-----|---|---|
| OUT → IN daisy chain | JST-PH 4-pin female-to-female | MakerSheet, Adafruit STEMMA |
| Controller feed | JST-PH 4-pin female-to-tinned pigtail | The Pi Hut, Adafruit |
| Power injection | JST-PH 2-pin red/black pigtail | generic |

> Off-the-shelf wire colors may differ — verify pin-1 → color per vendor before wiring.

## On-board passives & protection (per segment)

| Ref | Part | Value | Qty | Status |
|-----|---|---|-----|---|
| `C*` | Bulk cap, per injection point | 100–470 µF | TBD | ⬜ |
| `C*` | Decoupling, per LED (or 1–4 LEDs) | 100 nF | TBD | ⬜ |
| `D*`/`Q*` | Reverse-polarity protection (**required**) | Schottky / P-MOSFET | TBD | ⬜ |

## Controller board (external — one per strand)

| Ref | Part | Value | Notes |
|-----|---|---|---|
| `R*` | Series R on DATA + CLK output | 33–100 Ω | Damp controller → first board |
| `F*` | Fuse / polyfuse | TBD | One per strand / injection feed |
| `TVS*` | ESD/TVS on DATA, CLK, VCC | TBD | Segments rely on LED internal ESD |
| — | Level shifter | 3.3 V → 5 V | Drives DATA + CLK into `J_IN` |

## To confirm

- [ ] Confirm SMD side-entry footprints match between JST (white) and the hanxia `J_OUT` header.

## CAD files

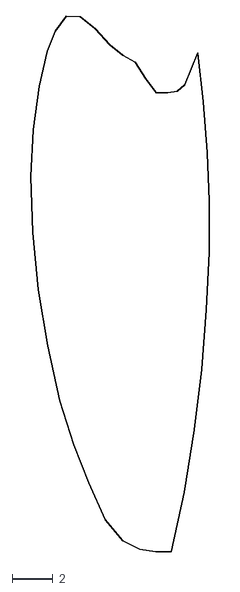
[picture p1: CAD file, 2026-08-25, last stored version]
investigations/feather-outline/out/dxf/feather_18.dxf
8.78 x 26.4

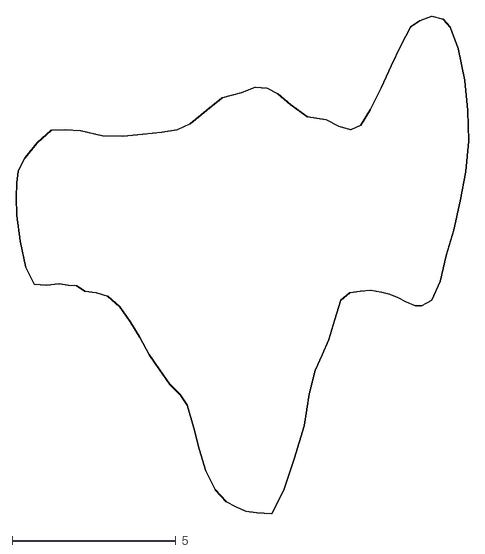
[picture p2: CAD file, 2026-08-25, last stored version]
investigations/feather-outline/out/dxf/feather_2.dxf
13.8 x 15.2

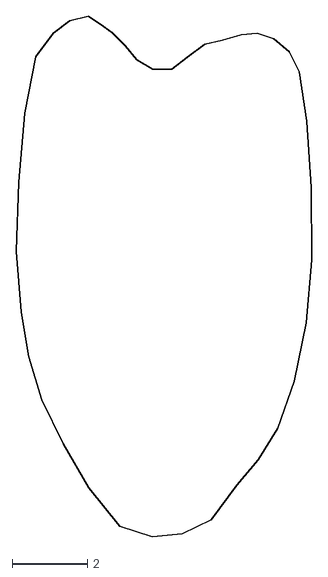
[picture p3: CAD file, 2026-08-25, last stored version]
investigations/feather-outline/out/dxf/feather_28.dxf
7.84 x 13.8

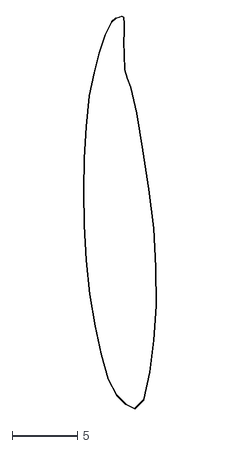
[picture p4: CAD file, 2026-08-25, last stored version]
investigations/feather-outline/out/dxf/feather_17.dxf
5.55 x 30.0

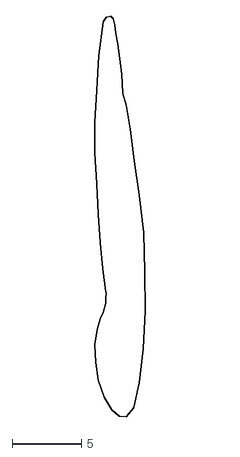
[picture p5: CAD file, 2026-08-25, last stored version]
investigations/feather-outline/out/dxf/feather_19.dxf
3.66 x 28.9

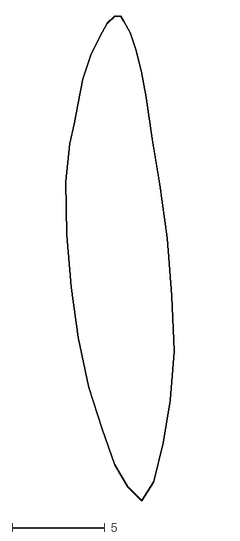
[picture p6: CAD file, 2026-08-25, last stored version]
investigations/feather-outline/out/dxf/feather_16.dxf
5.84 x 26.1

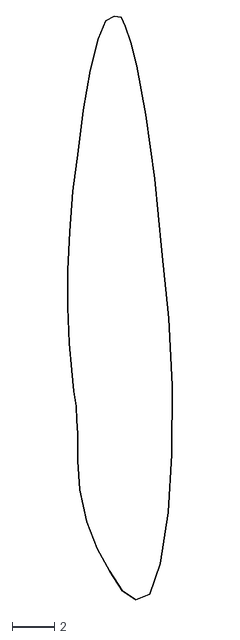
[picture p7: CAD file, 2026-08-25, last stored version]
investigations/feather-outline/out/dxf/feather_15.dxf
4.95 x 27.6

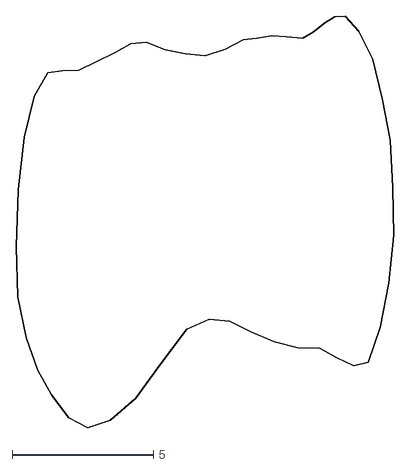
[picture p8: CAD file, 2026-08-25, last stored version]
investigations/feather-outline/out/dxf/feather_26.dxf
13.4 x 14.6

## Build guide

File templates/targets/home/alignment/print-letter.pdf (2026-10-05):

### assembly-template right

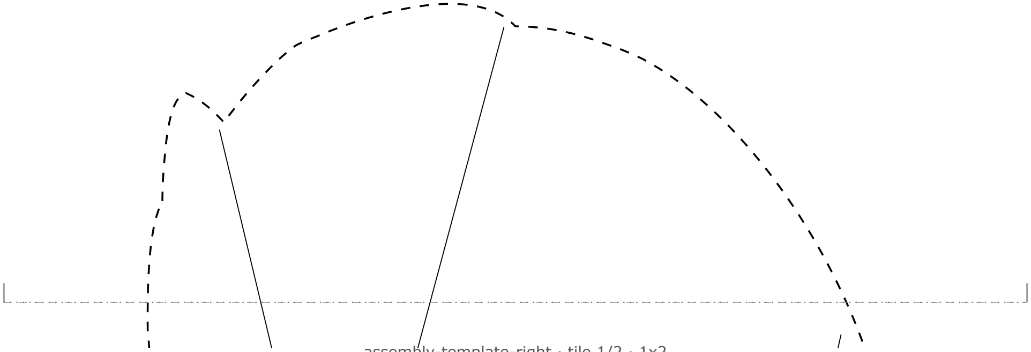
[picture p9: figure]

assembly-template-right · tile 1/2 · 1x2

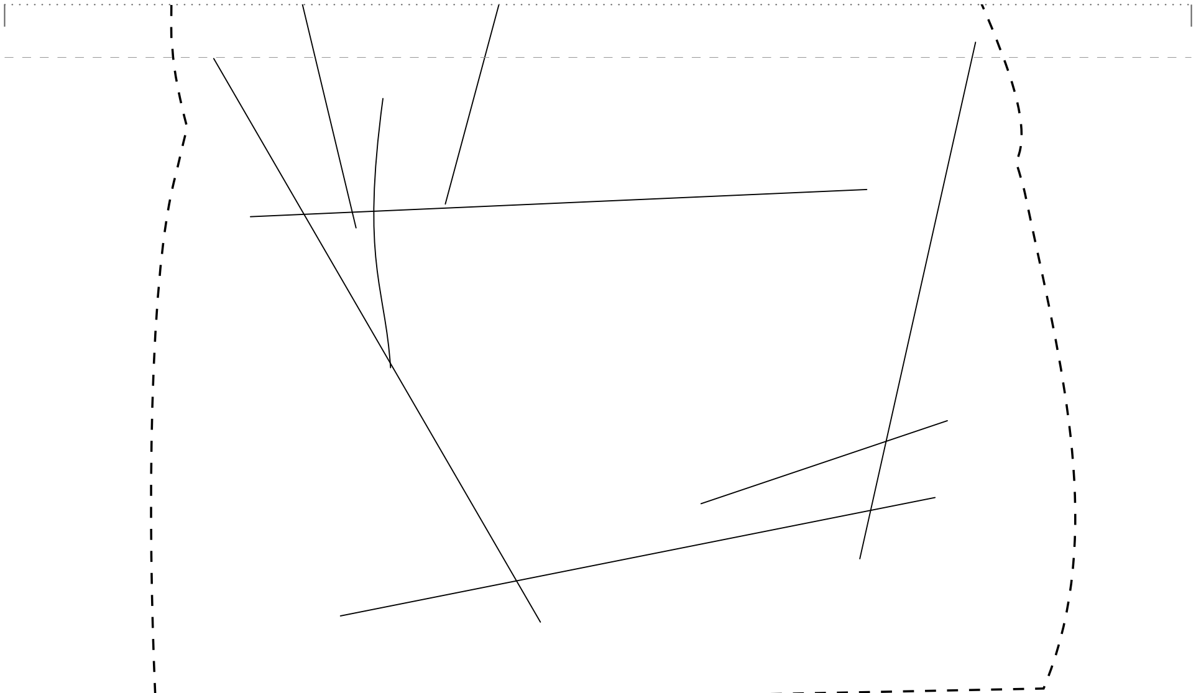
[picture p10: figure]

assembly-template-right · tile 2/2 · 1x2

### assembly-template left

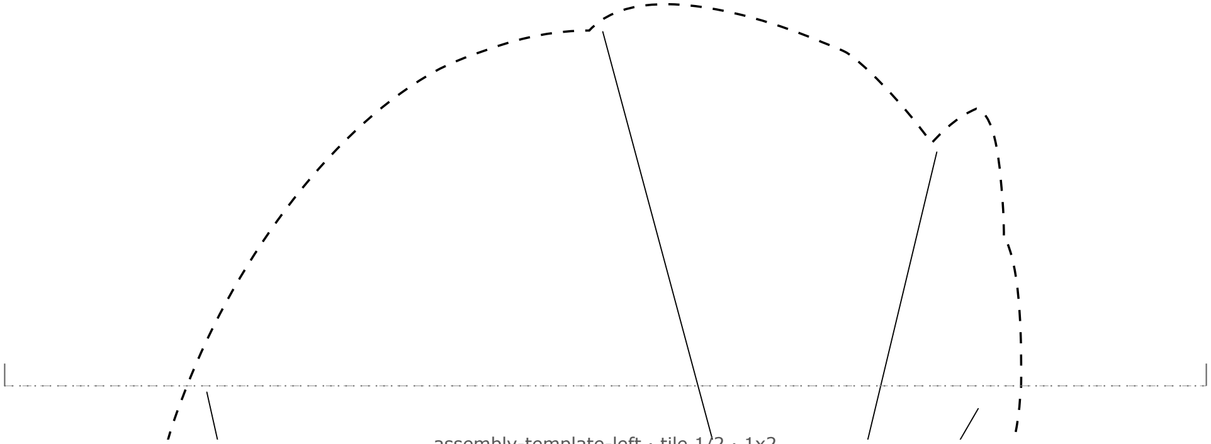
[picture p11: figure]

assembly-template-left · tile 1/2 · 1x2

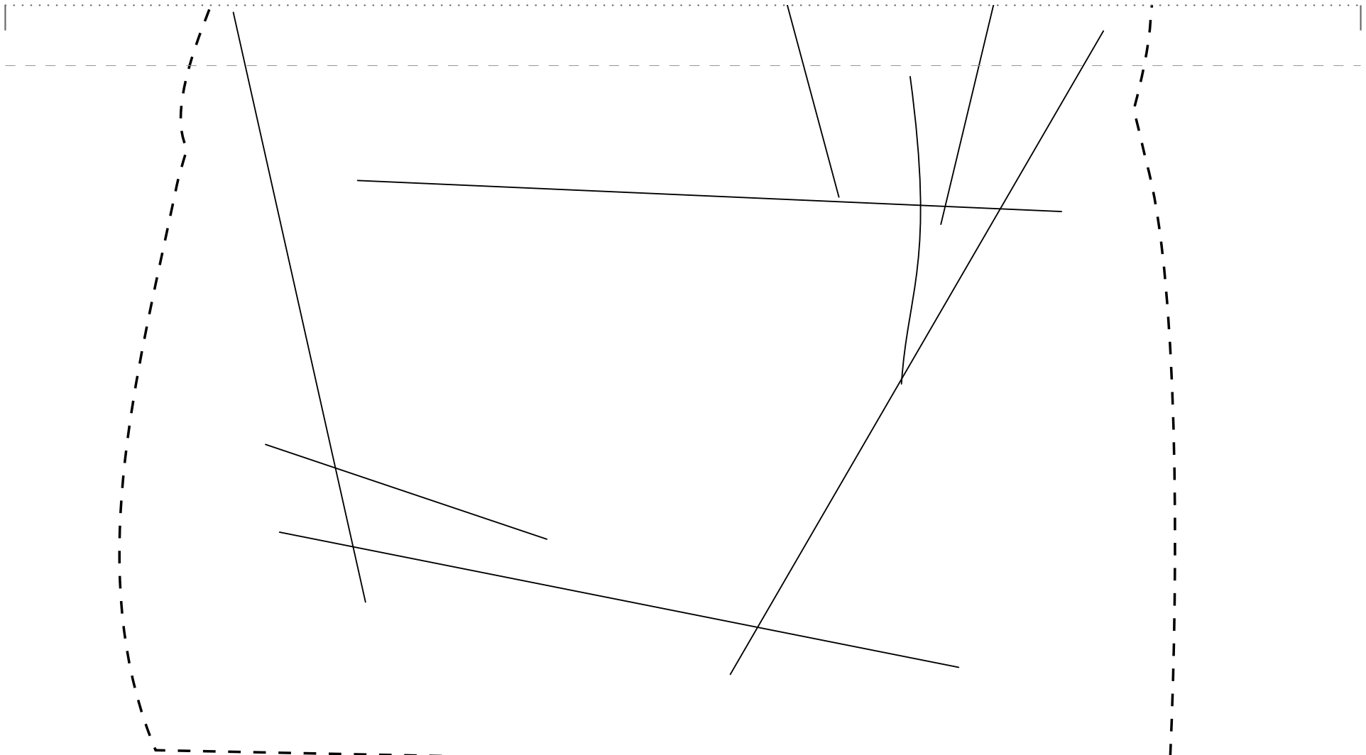
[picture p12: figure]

assembly-template-left · tile 2/2 · 1x2

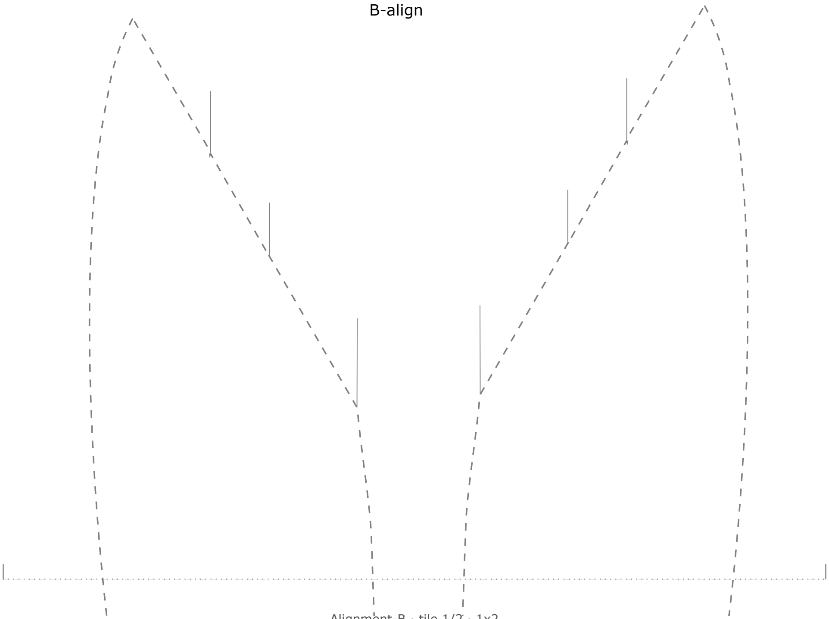
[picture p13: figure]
B-align

Alignment-B · tile 1/2 · 1x2

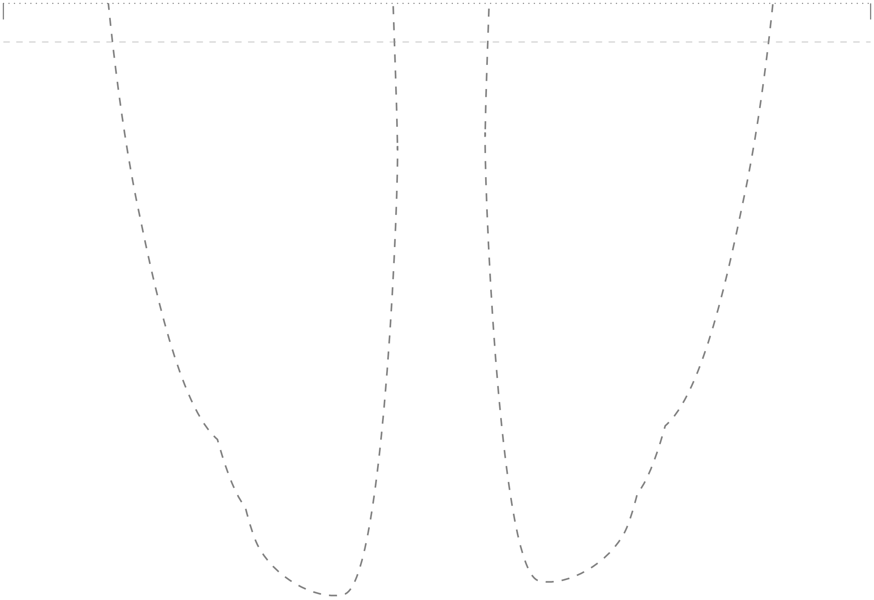
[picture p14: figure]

Alignment-B · tile 2/2 · 1x2

### P Right

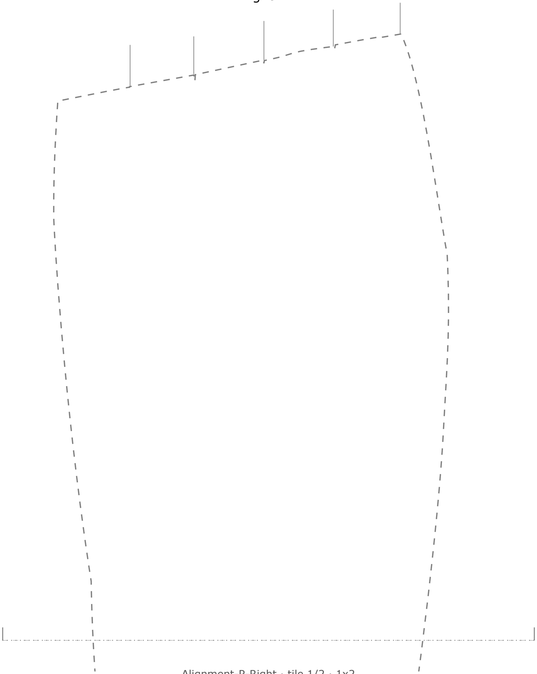
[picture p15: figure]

Alignment-P-Right · tile 1/2 · 1x2

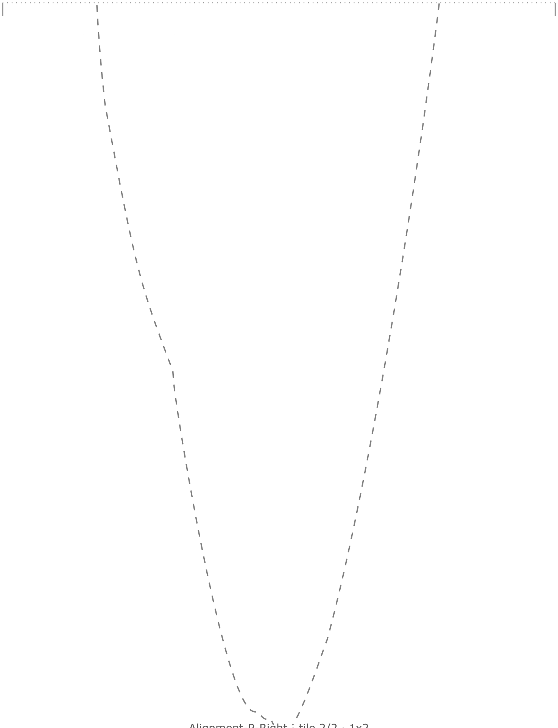
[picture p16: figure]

Alignment-P-Right · tile 2/2 · 1x2

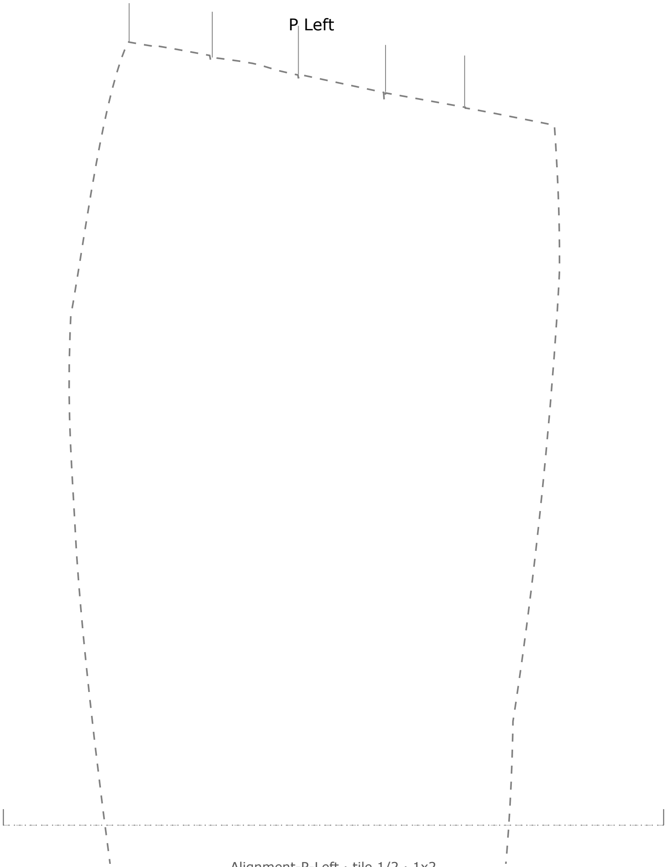
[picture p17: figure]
P Left

Alignment-P-Left · tile 1/2 · 1x2

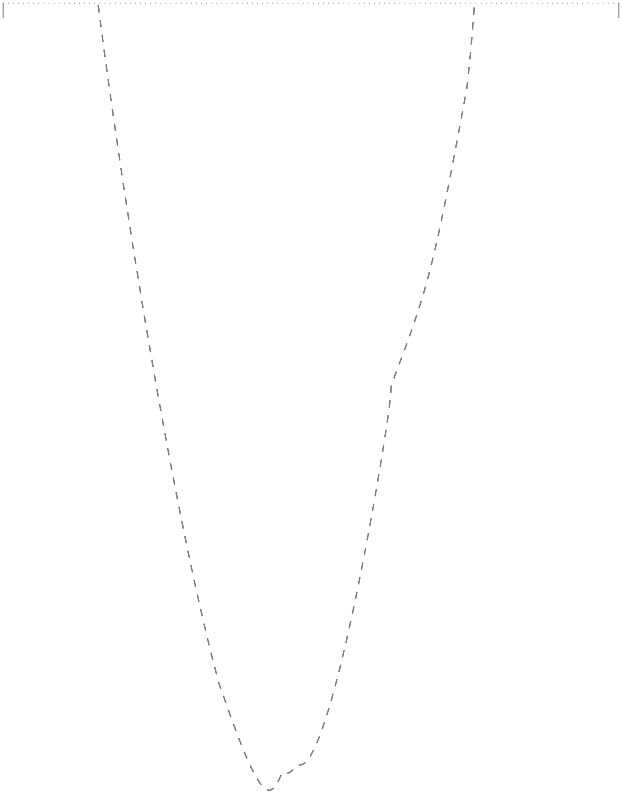
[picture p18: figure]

Alignment-P-Left · tile 2/2 · 1x2

PC-align | A-align

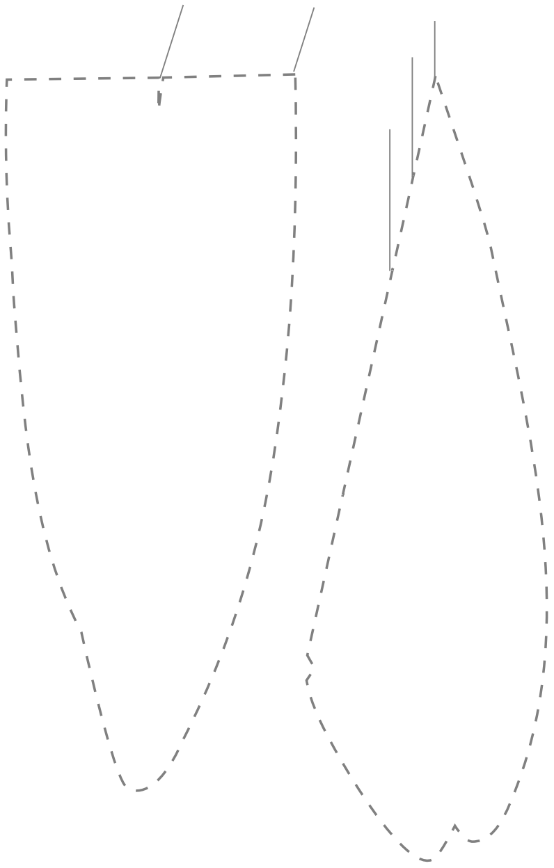
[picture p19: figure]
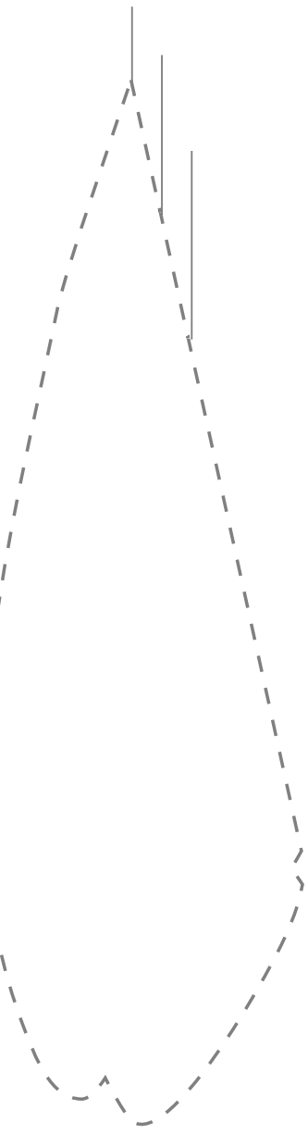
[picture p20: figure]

### SC-align

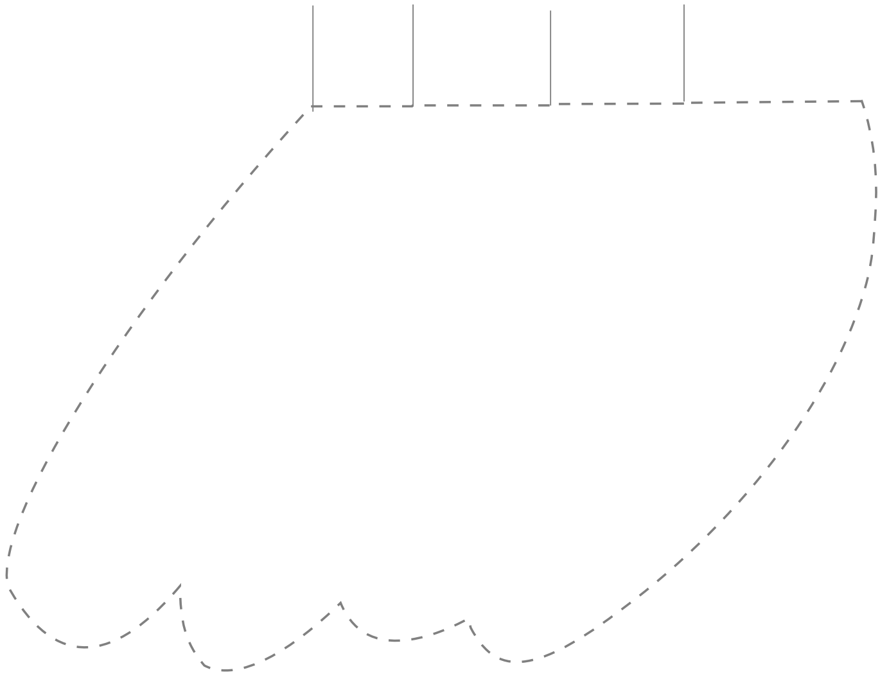
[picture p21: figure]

### SC-align

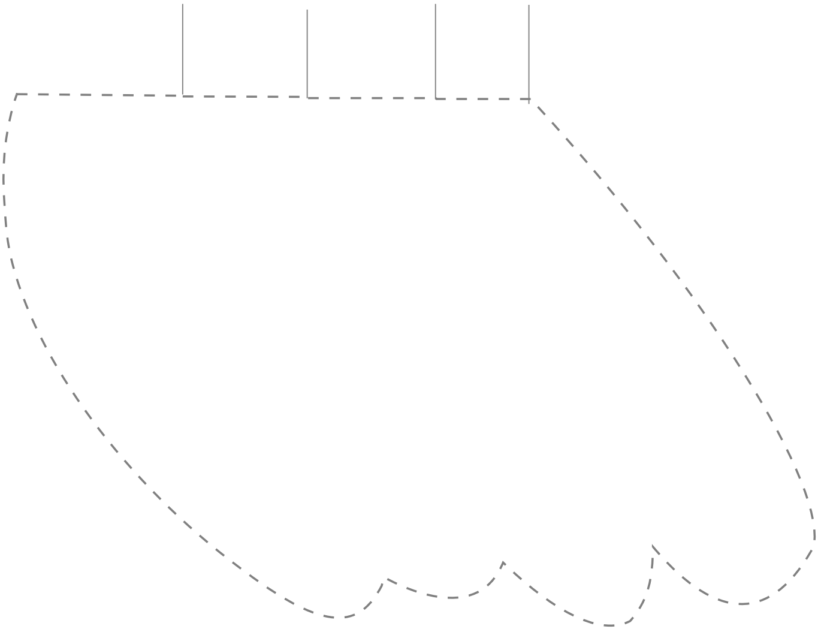
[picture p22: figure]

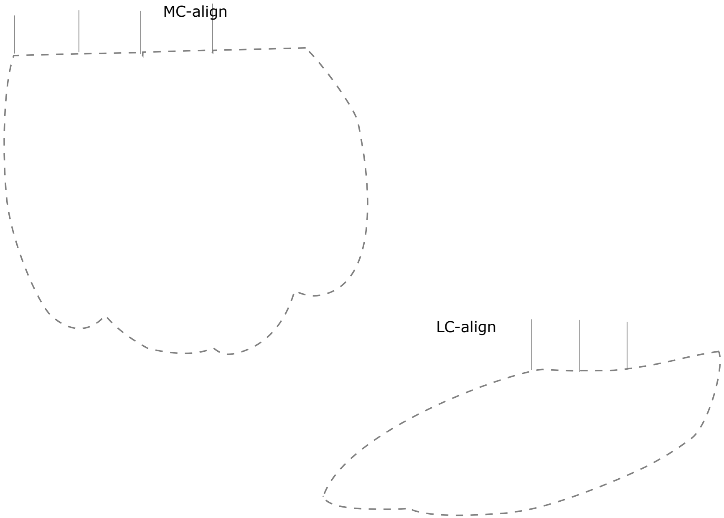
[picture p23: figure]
MC-align; LC-align

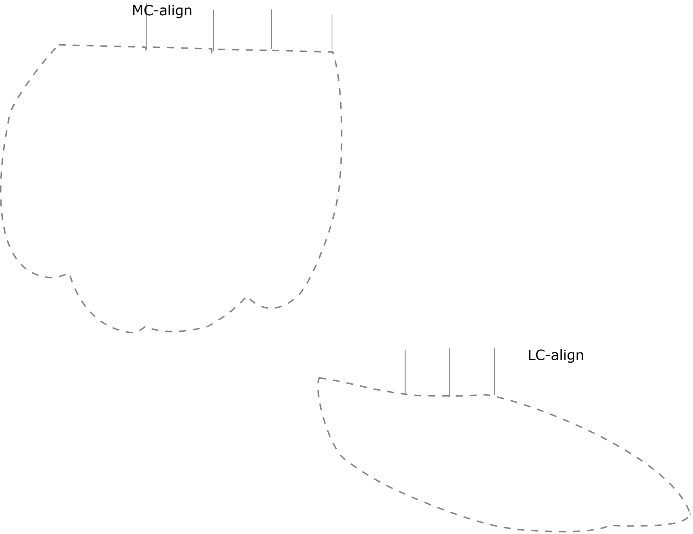
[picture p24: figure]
MC-align; LC-align

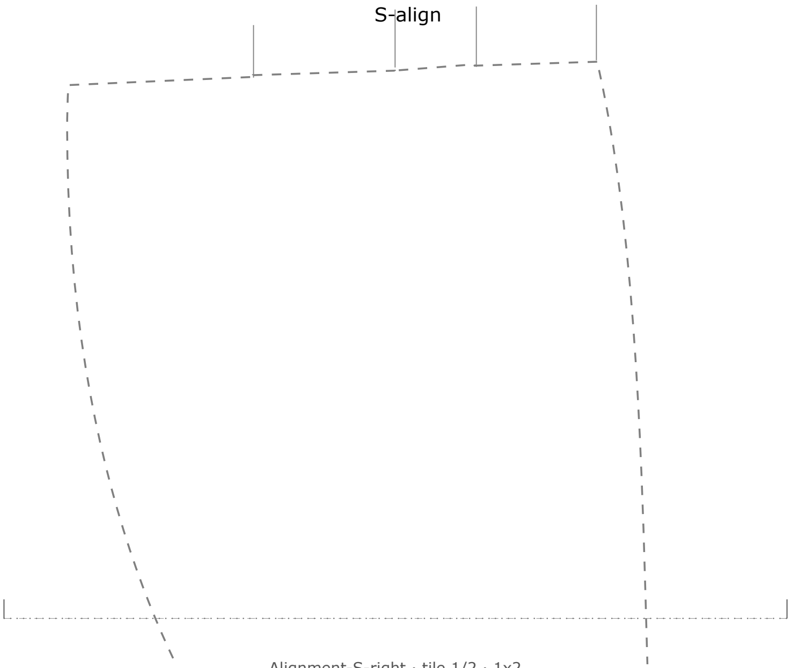
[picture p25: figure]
S-align

Alignment-S-right · tile 1/2 · 1x2

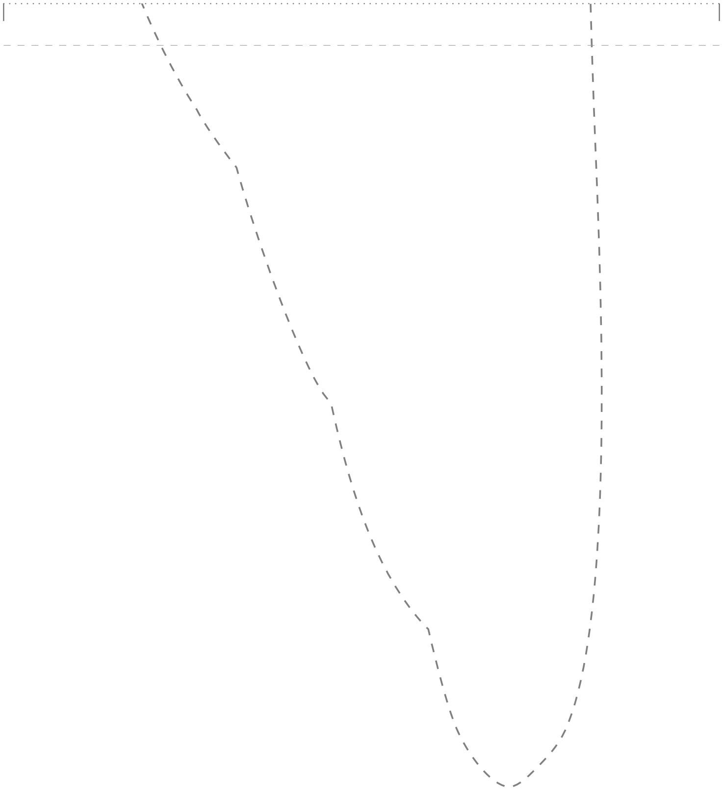
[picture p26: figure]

Alignment-S-right · tile 2/2 · 1x2

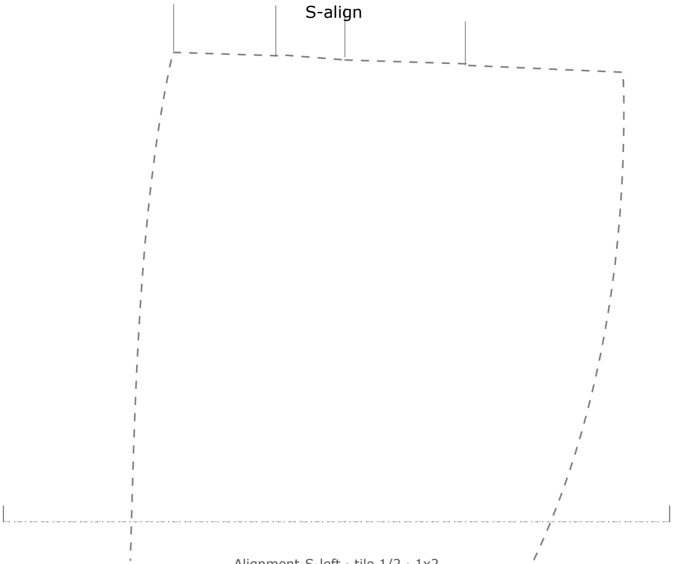
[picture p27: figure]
S-align

Alignment-S-left · tile 1/2 · 1x2

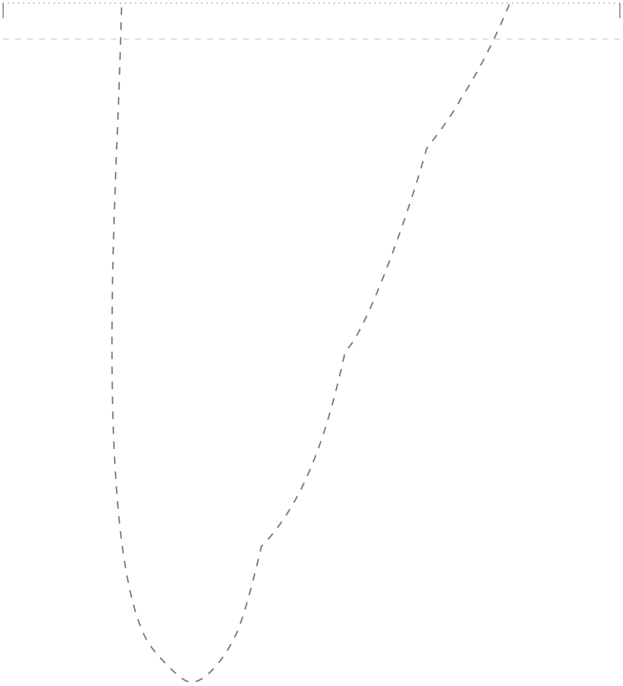
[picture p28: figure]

Alignment-S-left · tile 2/2 · 1x2

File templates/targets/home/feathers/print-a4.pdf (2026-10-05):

# Feather templates

Print at 100% / actual size.

50mm
2in

Do not fit or scale.

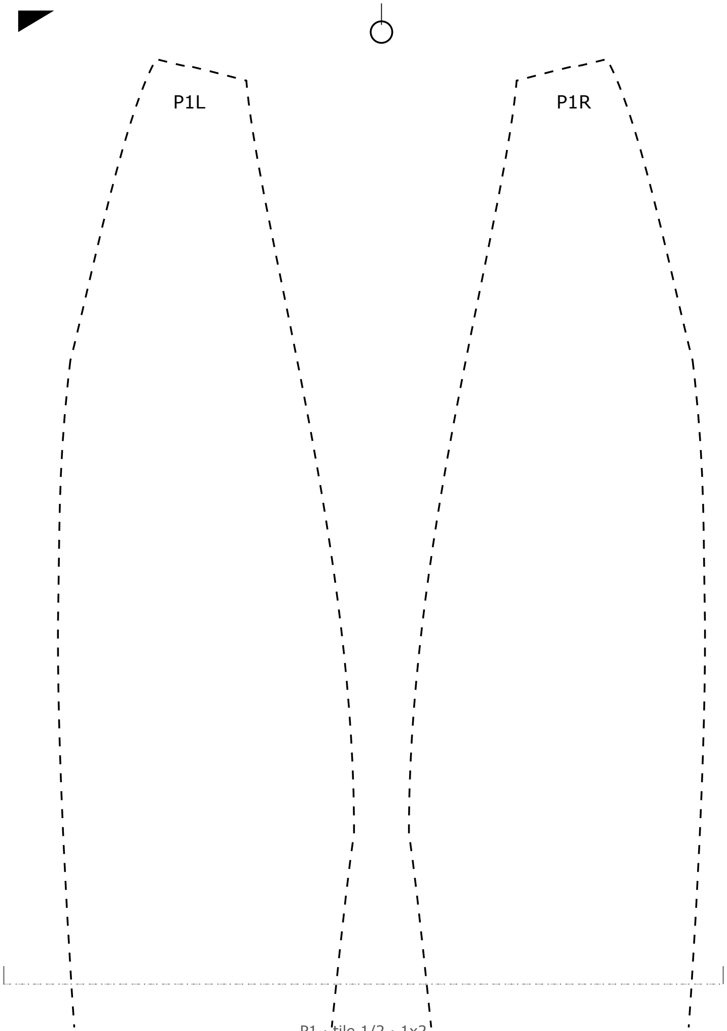
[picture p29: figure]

P1 · tile 1/2 · 1x2

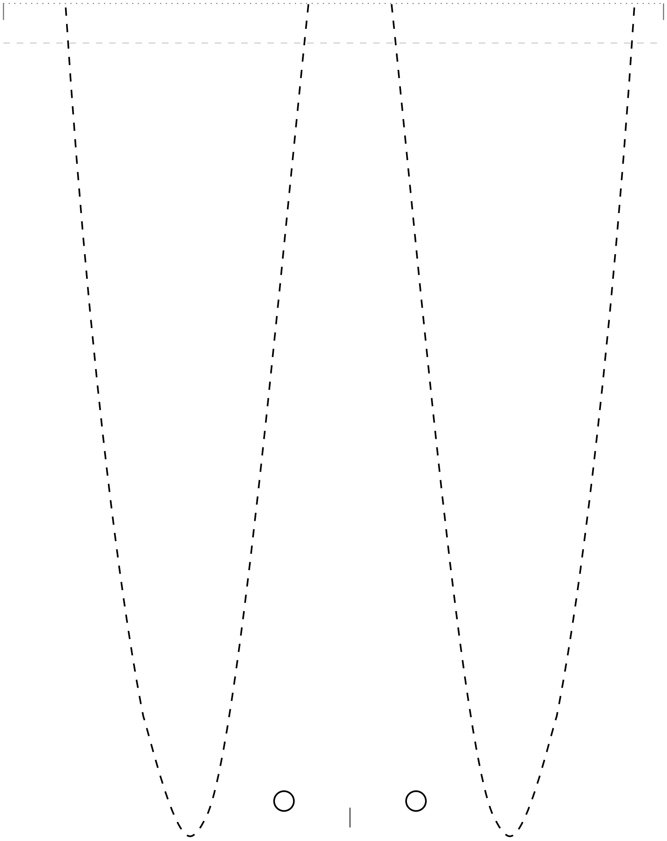
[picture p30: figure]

P1 · tile 2/2 · 1x2

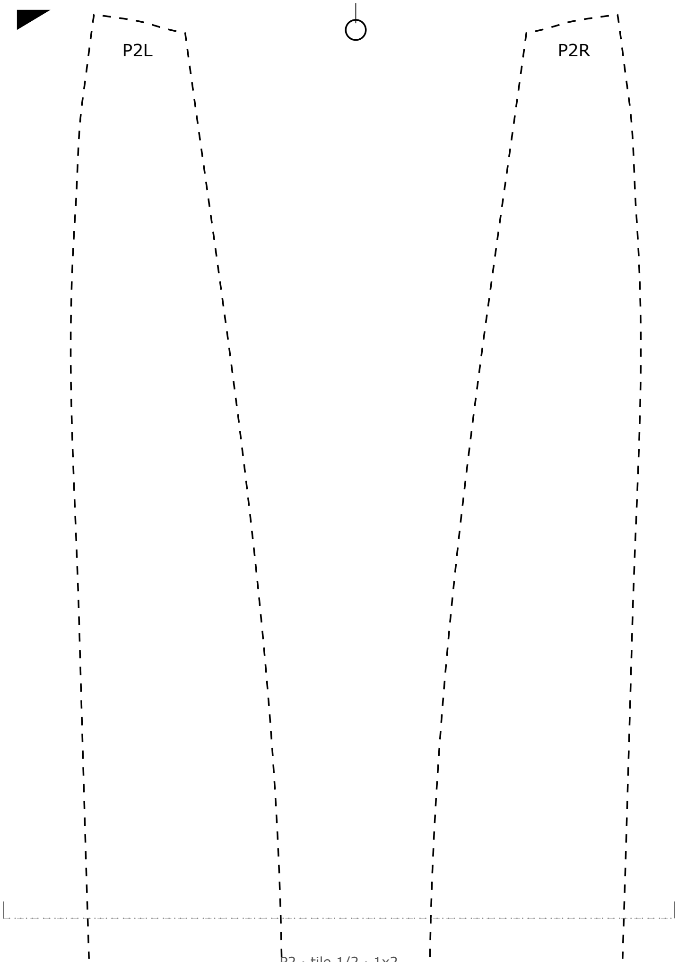
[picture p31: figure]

P2 · tile 1/2 · 1x2

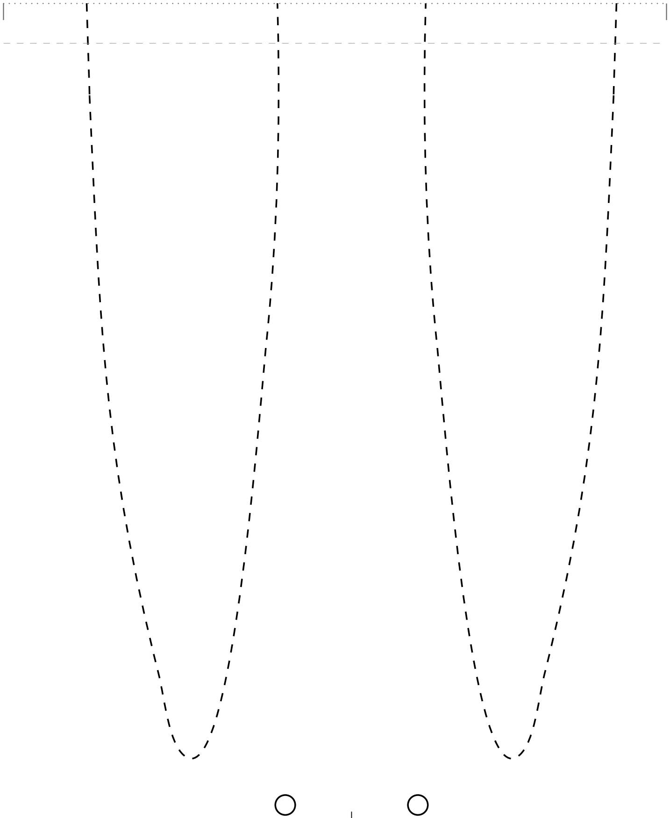
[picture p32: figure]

P2 · tile 2/2 · 1x2

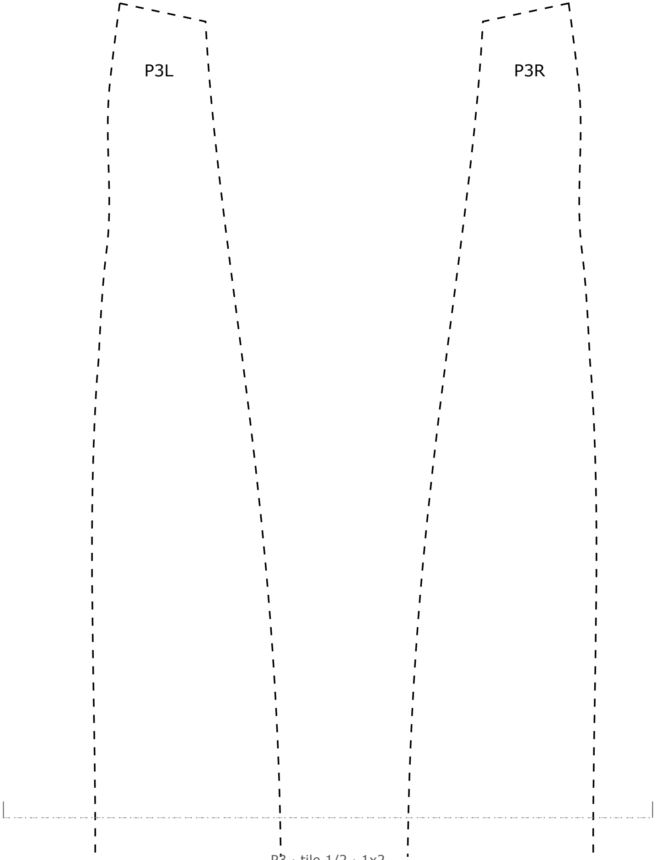
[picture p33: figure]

P3 · tile 1/2 · 1x2

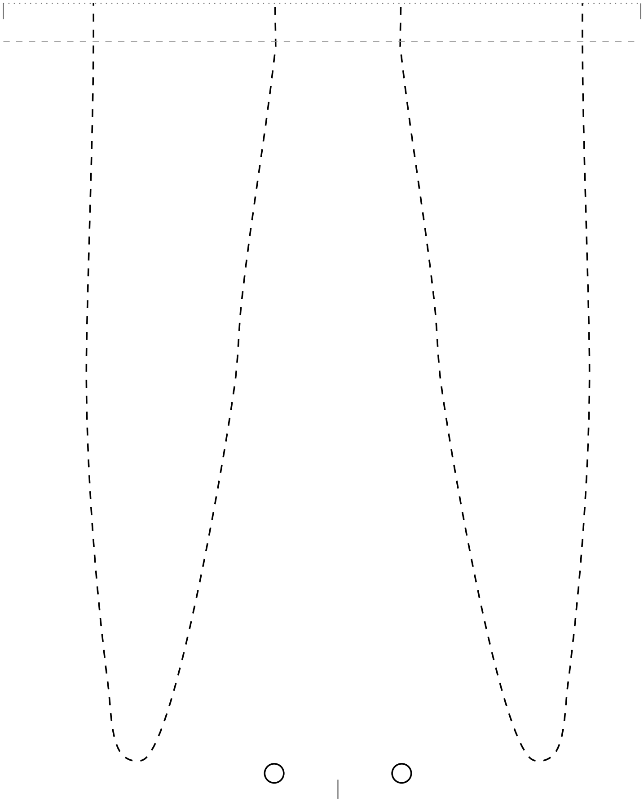
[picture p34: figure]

P3 · tile 2/2 · 1x2

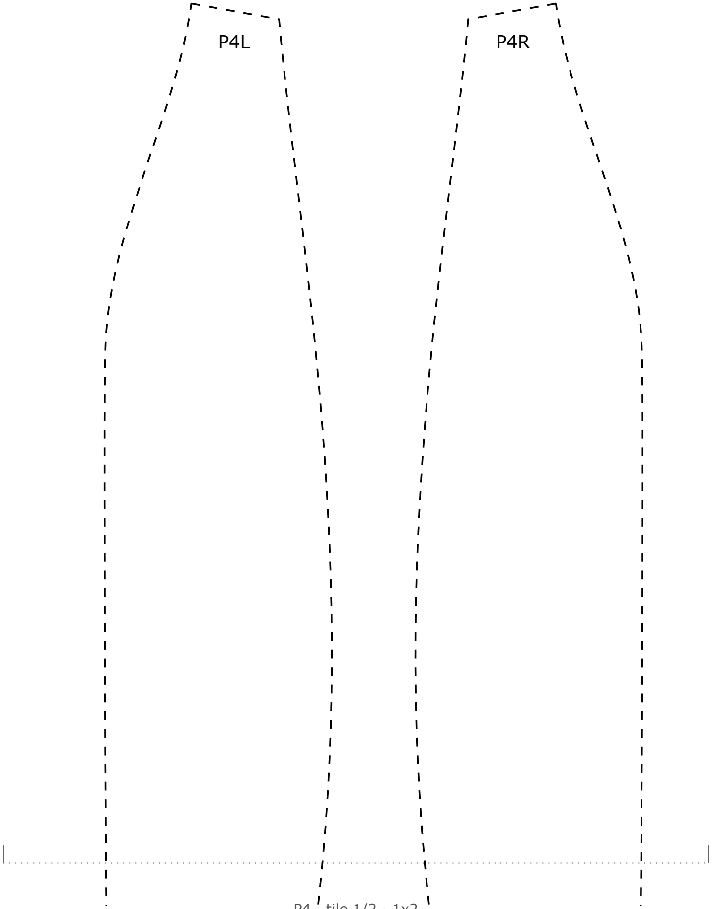
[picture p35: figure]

P4 · tile 1/2 · 1x2

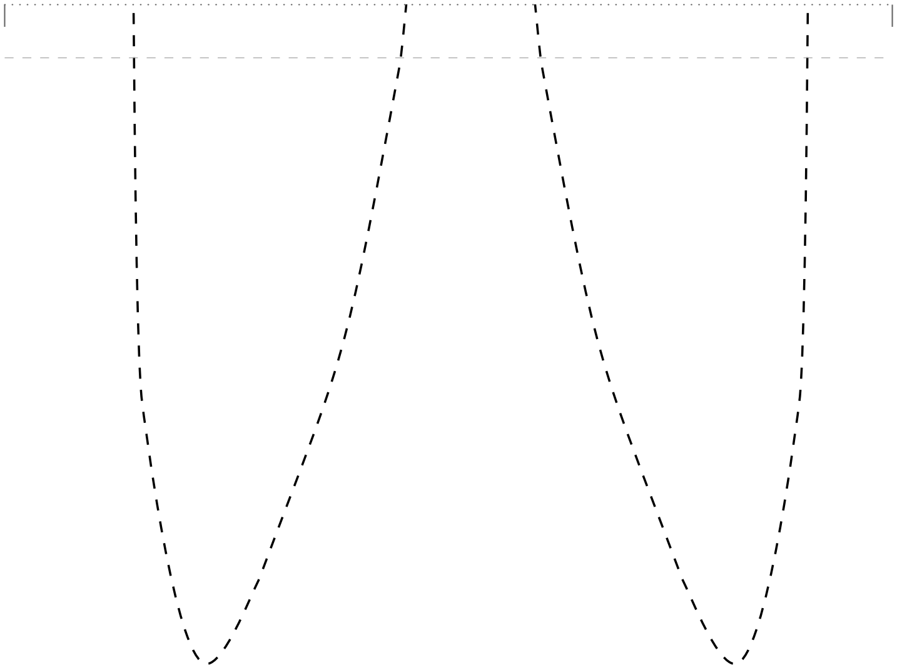
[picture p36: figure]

P4 · tile 2/2 · 1x2

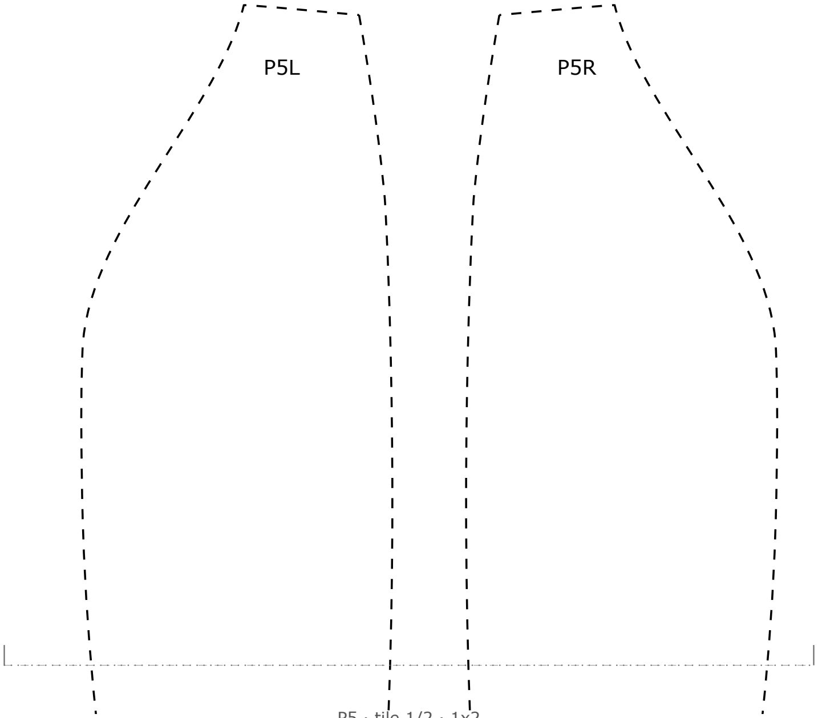
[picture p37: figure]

P5 · tile 1/2 · 1x2

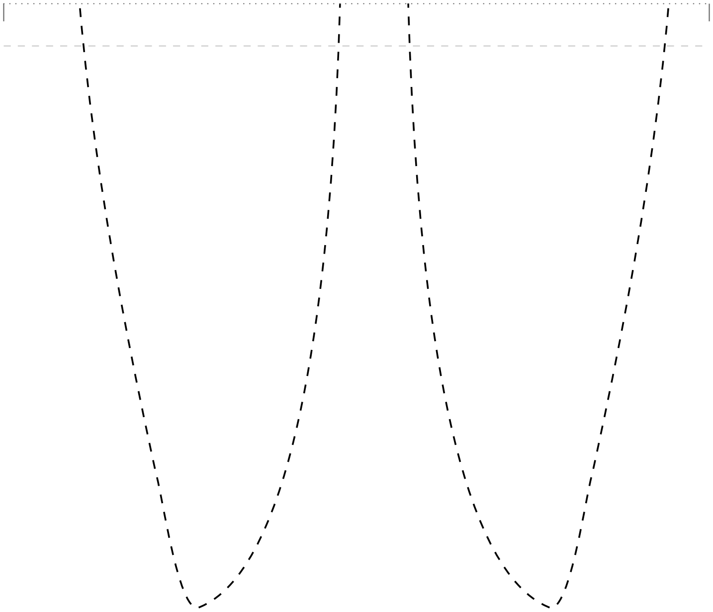
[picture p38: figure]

P5 · tile 2/2 · 1x2

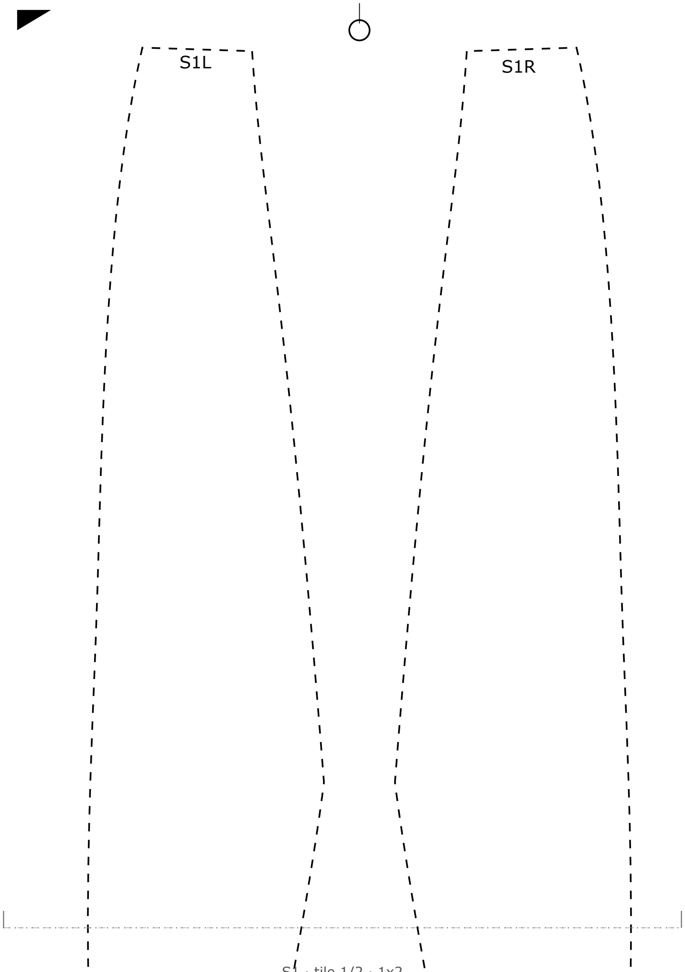
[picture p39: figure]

S1 · tile 1/2 · 1x2

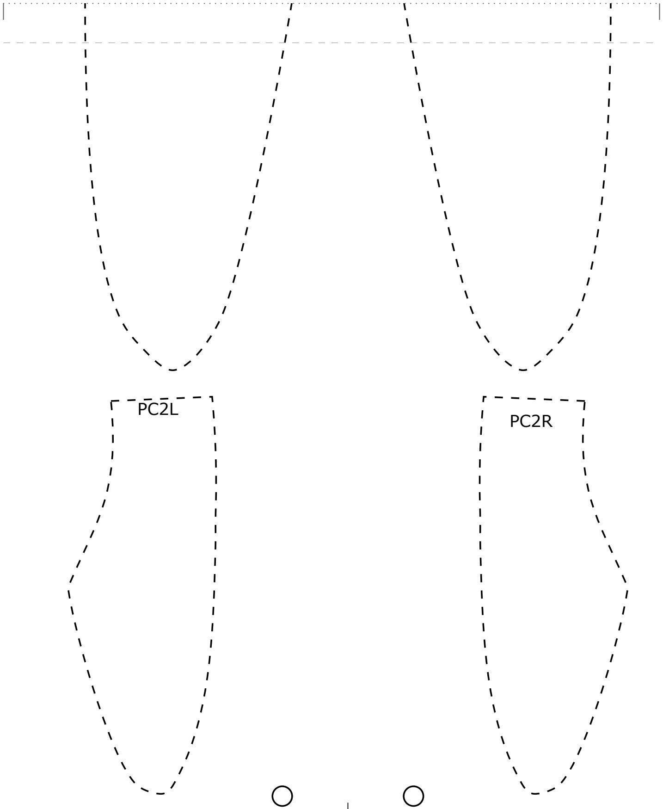
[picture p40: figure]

S1 · tile 2/2 · 1x2

S2R

### PC1R

### PC1L

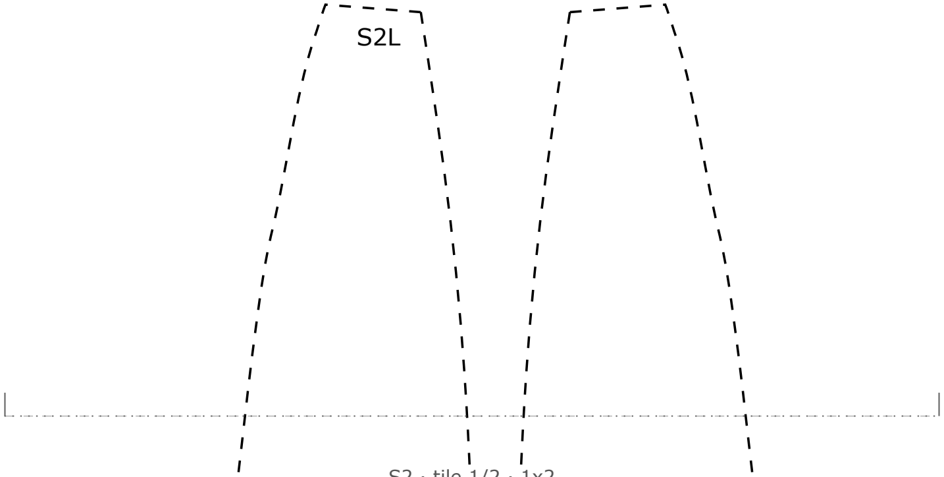
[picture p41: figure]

S2 · tile 1/2 · 1x2

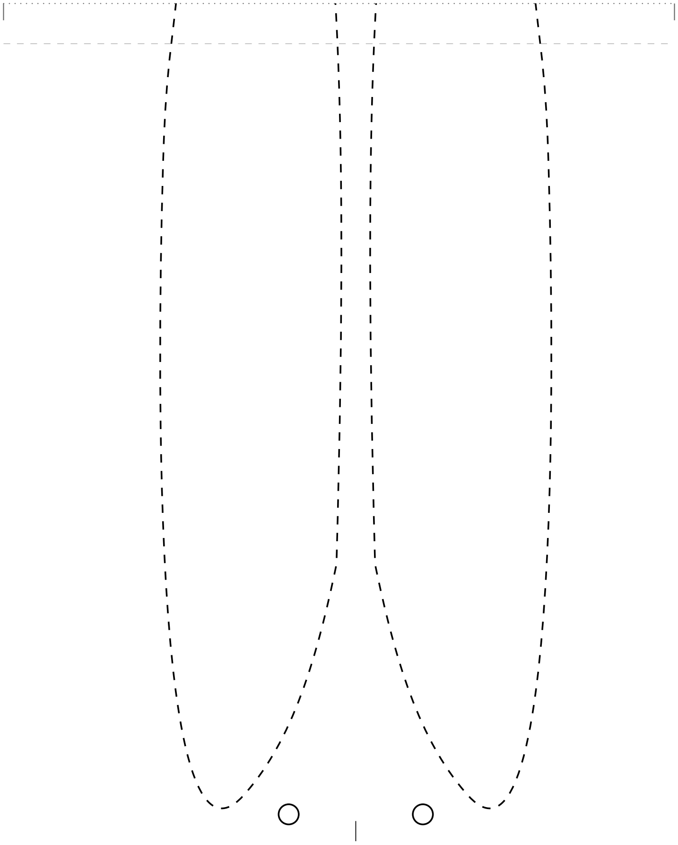
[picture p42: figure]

S2 · tile 2/2 · 1x2

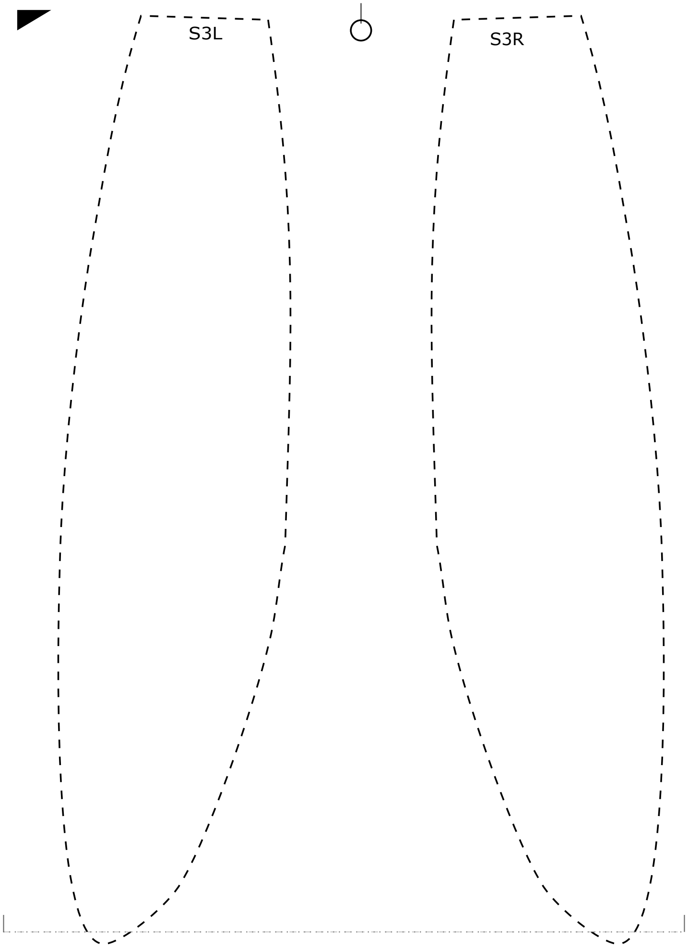
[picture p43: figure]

S3 · tile 1/2 · 1x2

S4R

S4L

S3 · tile 2/2 · 1x2

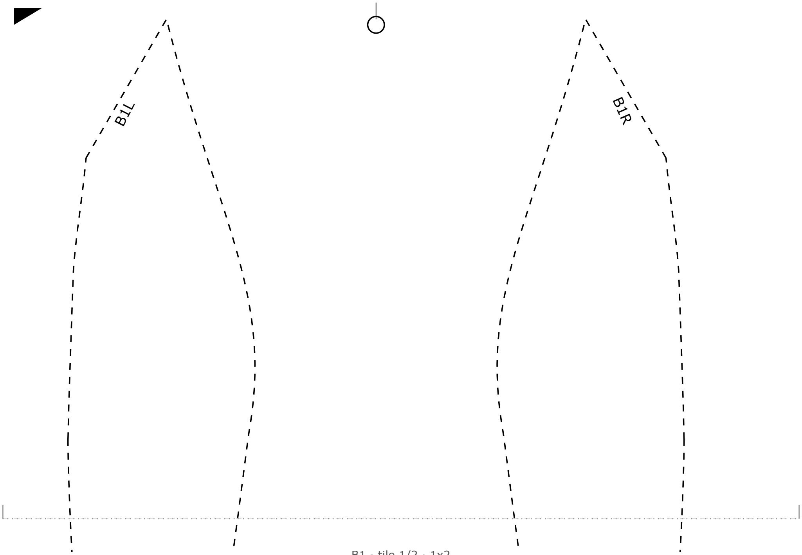
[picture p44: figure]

B1 · tile 1/2 · 1x2

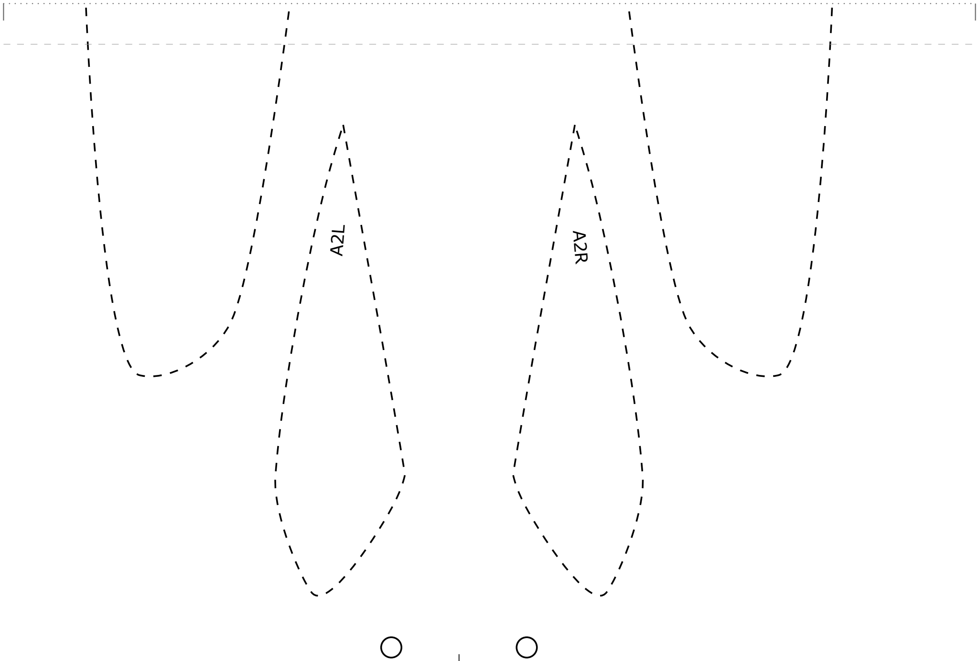
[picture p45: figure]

B1 · tile 2/2 · 1x2

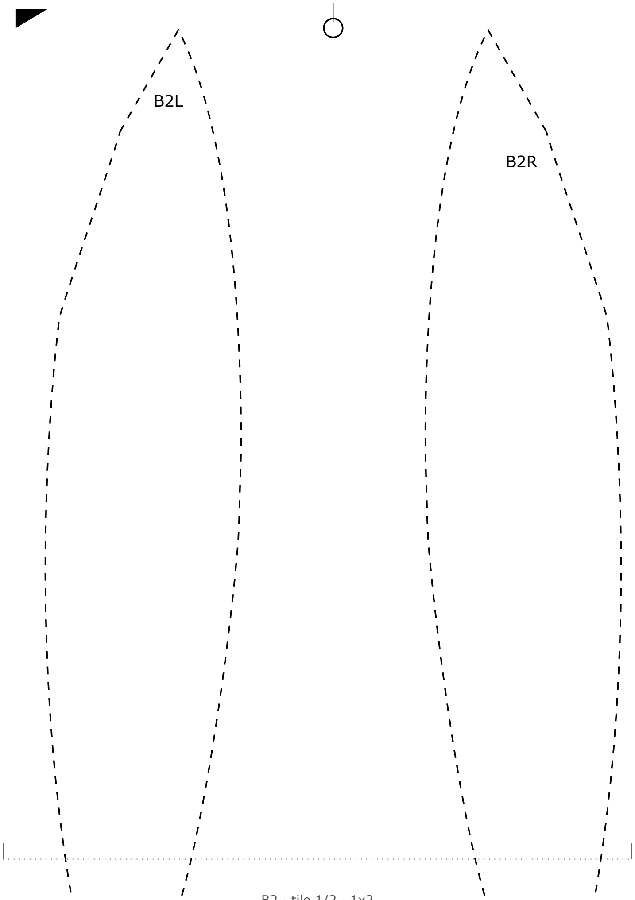
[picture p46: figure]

B2 · tile 1/2 · 1x2

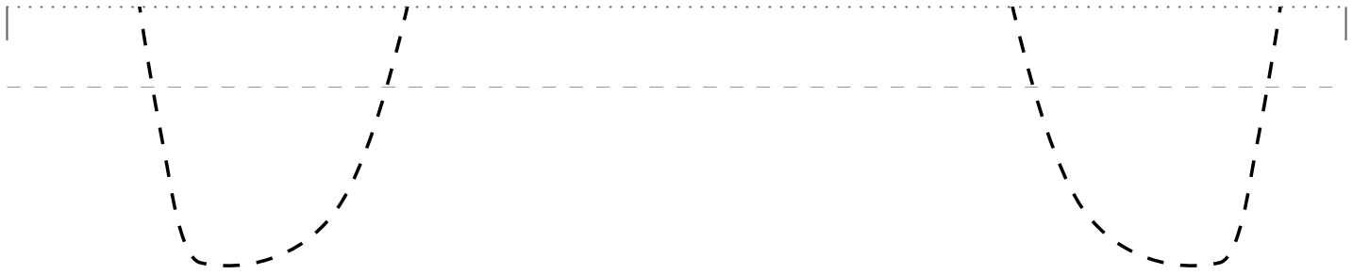
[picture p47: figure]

A1R A1L

B2 · tile 2/2 · 1x2

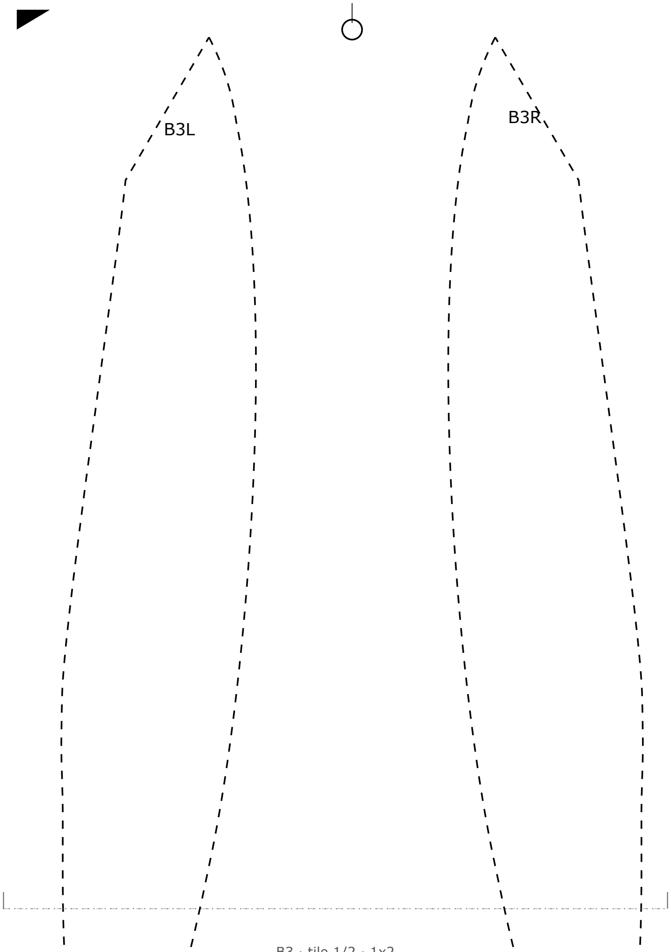
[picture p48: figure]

B3 · tile 1/2 · 1x2


A3L

A3R

B3 · tile 2/2 · 1x2


SC1-SC2 · tile 1/2 · 1x2


SC1-SC2 · tile 2/2 · 1x2

MC1R
MC1L


MC1-MC2 · tile 1/2 · 1x2

MC3R

MC4R

MC3L

### MC4L

MC1-MC2 · tile 2/2 · 1x2

### LC1R

### LC2R

### LC3R

### LC1L

### LC2L

### LC3L

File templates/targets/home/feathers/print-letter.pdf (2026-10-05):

# Feather templates

Print at 100% / actual size.

50mm
2in

Do not fit or scale.


P1 · tile 1/2 · 1x2


P1 · tile 2/2 · 1x2


P2 · tile 1/2 · 1x2


P2 · tile 2/2 · 1x2


P3 · tile 1/2 · 1x2


P3 · tile 2/2 · 1x2


P4 · tile 1/2 · 1x2


P4 · tile 2/2 · 1x2


P5 · tile 1/2 · 1x2


P5 · tile 2/2 · 1x2


S1 · tile 1/2 · 1x2


S1 · tile 2/2 · 1x2

S2R

### PC1R

### PC1L


S2 · tile 1/2 · 1x2


S2 · tile 2/2 · 1x2


S3 · tile 1/2 · 1x2

S4R

S4L

S3 · tile 2/2 · 1x2


B1 · tile 1/2 · 1x2


B1 · tile 2/2 · 1x2


B2 · tile 1/2 · 1x2


A1R A1L

B2 · tile 2/2 · 1x2


B3 · tile 1/2 · 1x2


A3L

A3R

B3 · tile 2/2 · 1x2


SC1-SC2 · tile 1/2 · 1x2


SC1-SC2 · tile 2/2 · 1x2

MC1R
MC1L


MC1-MC2 · tile 1/2 · 1x2

MC3R

MC4R

MC3L

### MC4L

MC1-MC2 · tile 2/2 · 1x2

### LC1R

### LC2R

### LC3R

### LC1L

### LC2L

### LC3L

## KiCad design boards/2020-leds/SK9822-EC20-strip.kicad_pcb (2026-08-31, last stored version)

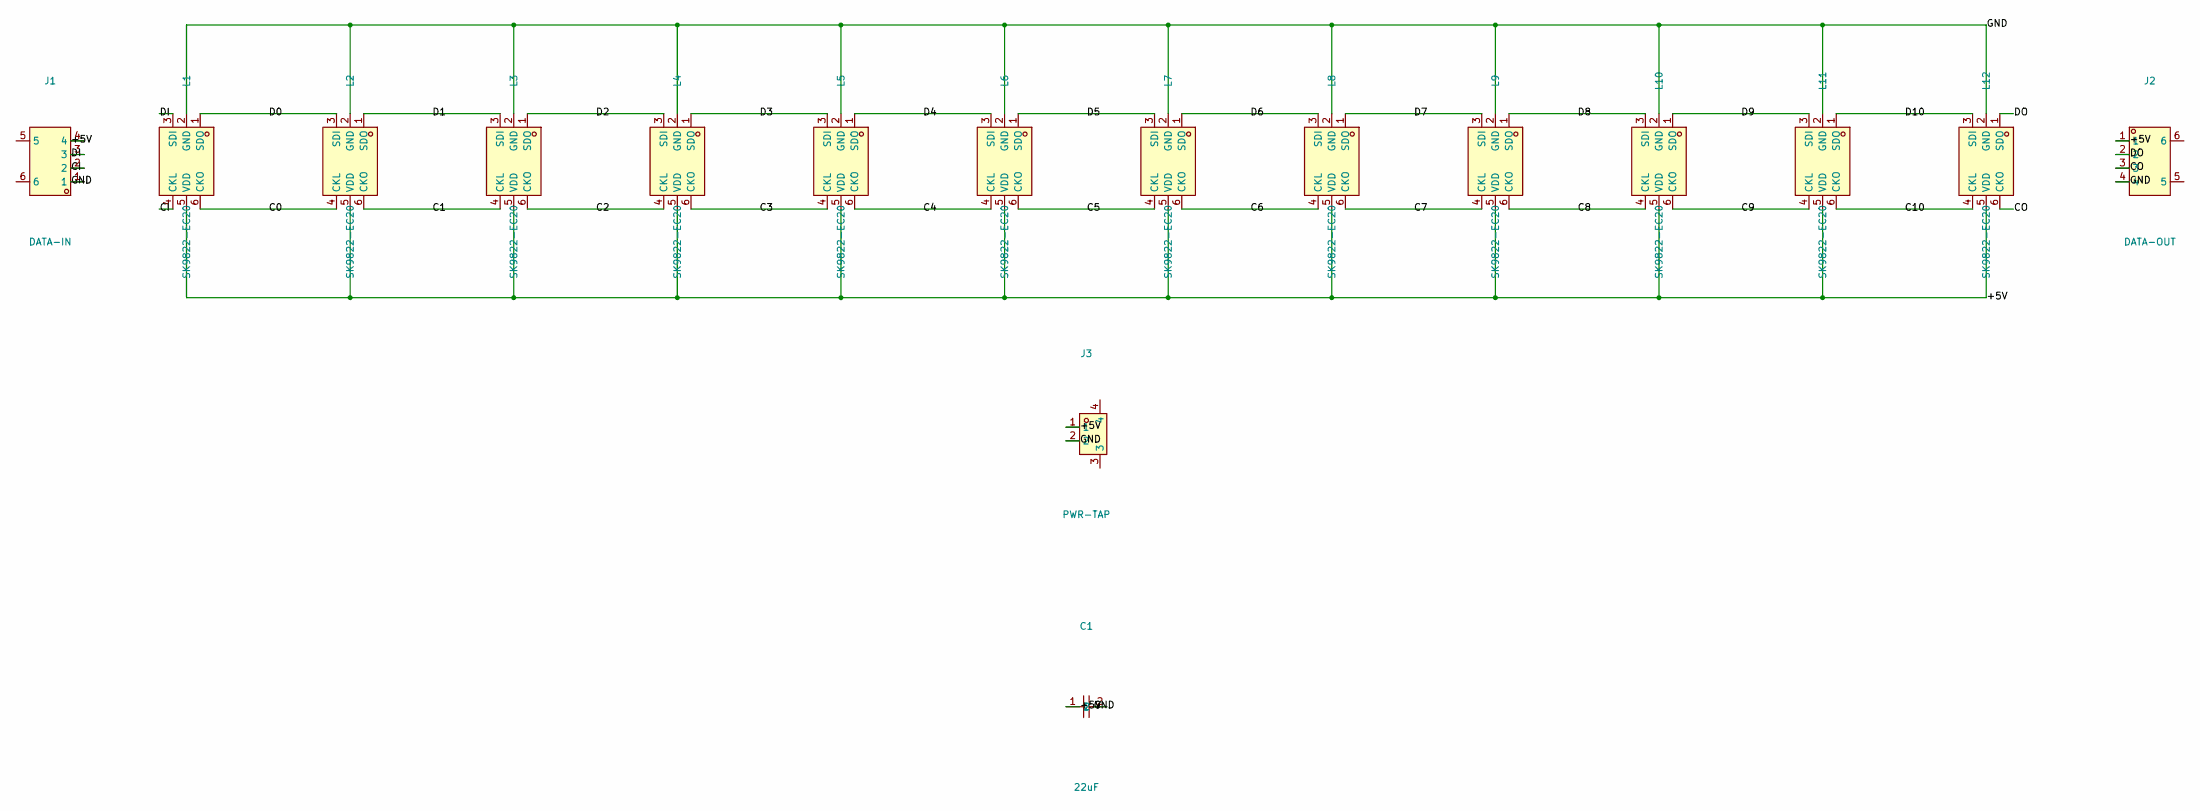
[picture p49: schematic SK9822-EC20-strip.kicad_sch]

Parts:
C1: 22uF; C1206
J1: DATA-IN; CONN-SMD_ZH1.5-4P_SMD
J2: DATA-OUT; CONN-SMD_ZH1.5-4P_SMD
J3: PWR-TAP; CONN-SMD_2P-P2.00_PH2.0-SPWB
L1, L2, L3, L4, L5, L6, L7, L8, L9, L10, L11, L12: SK9822-EC20; LED-SMD_6P-L2.0-W2.0-P0.80-TL

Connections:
/+5V: C1.1, J1.4, J2.1, J3.1, L1.5 (VDD), L2.5 (VDD), L3.5 (VDD), L4.5 (VDD), L5.5 (VDD), L6.5 (VDD), L7.5 (VDD), L8.5 (VDD), L9.5 (VDD), L10.5 (VDD), L11.5 (VDD), L12.5 (VDD)
/C0: L1.6 (CKO), L2.4 (CKL)
/C1: L2.6 (CKO), L3.4 (CKL)
/C2: L3.6 (CKO), L4.4 (CKL)
/C3: L4.6 (CKO), L5.4 (CKL)
/C4: L5.6 (CKO), L6.4 (CKL)
/C5: L6.6 (CKO), L7.4 (CKL)
/C6: L7.6 (CKO), L8.4 (CKL)
/C7: L8.6 (CKO), L9.4 (CKL)
/C8: L9.6 (CKO), L10.4 (CKL)
/C9: L10.6 (CKO), L11.4 (CKL)
/C10: L11.6 (CKO), L12.4 (CKL)
/CI: J1.2, L1.4 (CKL)
/CO: J2.3, L12.6 (CKO)
/D0: L1.1 (SDO), L2.3 (SDI)
/D1: L2.1 (SDO), L3.3 (SDI)
/D2: L3.1 (SDO), L4.3 (SDI)
/D3: L4.1 (SDO), L5.3 (SDI)
/D4: L5.1 (SDO), L6.3 (SDI)
/D5: L6.1 (SDO), L7.3 (SDI)
/D6: L7.1 (SDO), L8.3 (SDI)
/D7: L8.1 (SDO), L9.3 (SDI)
/D8: L9.1 (SDO), L10.3 (SDI)
/D9: L10.1 (SDO), L11.3 (SDI)
/D10: L11.1 (SDO), L12.3 (SDI)
/DI: J1.3, L1.3 (SDI)
/DO: J2.2, L12.1 (SDO)
/GND: C1.2, J1.1, J2.4, J3.2, L1.2 (GND), L2.2 (GND), L3.2 (GND), L4.2 (GND), L5.2 (GND), L6.2 (GND), L7.2 (GND), L8.2 (GND), L9.2 (GND), L10.2 (GND), L11.2 (GND), L12.2 (GND)

Board: 2 copper layers, 16 parts (0 on the bottom side), 28 nets, no tracks yet.

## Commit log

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2026-08-24 Consolidate boards into one core-ideas + settled-parts doc
    - boards/: single README with core ideas, locked decisions, and settled part numbers; delete per-board folders (controller, led-segment incl. fritzing part, power-hub)
    - covert strip chains: 4-pin connectors carrying power + data
    - controller: one central Pixelblaze V3 (ElectroMage) driving both wings, settled
    - investigations/topology/: deleted as done; split power/data decision, routing, and 12 V drop-budget rationale captured in boards doc
    - fix dangling links in root/mechanical/investigations readmes and connector-pinout doc; update stale path comment in easyeda_to_fritzing.py
2026-08-24 feather: establish programmatic data layer for outline templates
    Fix the §2 scale contradiction (locked to 1 unit = 0.75 cm, P4 = 75 cm),
    enumerate per-feather greater-covert templates in §3.4, add placeholder
    median/lesser/marginal covert rows, and add §8 documenting the
    source-of-truth data file + generator scheme. Markdown tables are to be
    generated or linted from the data file to prevent drift.
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2026-08-24 feather: fully enumerate covert rows, remove board language from templates
    outline-templates.md is geometry-only; §3.4b had leaked electrical wording
    ('chains of short boards', 'shared strip', a Lit? column) and left the
    median/lesser/marginal coverts as 'several per row' placeholders. Replace
    with full per-feather enumeration (MD1-12, LS1-1..LS3-12, MG1-12), each with
    total/vane/tip derived from Sn (0.4 / 0.30 / 0.24 / 0.18 / 0.14 x Sn, marked
    estimates). Update §4 layering to the new IDs, strip the inline 'lit
    individually' from the alula section, and point lighting/grouping concerns
    at lighting-and-boards.md. Sync the generator backlog's feathers.json task.
2026-08-24 feather: lock §5 decisions, scope out diffuser + bay-access items
    Confirm width-look via --vane-ratio-adjustment on the preview sheet,
    hem clearance/panel height (P4=75 cm, 50x75 panel), wing-columns layout,
    and single mirrored master. Set working shingle overlap at ~30% of the
    covered feather's length (knob, revisit on preview). Mark diffuser
    geometry (investigations/diffuser-halo) and electronics-bay access
    (mechanical/structural) out of scope for the template doc. Sync the
    arrangement-engine backlog to the locked decisions.
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2026-08-24 feather: geometry engine G2 — core listable geometry + pytest infra
    Add feathergen package with pure-math geometry primitives in cm: Point
    tuples, polyline length/bbox, translate/rotate/reflect_vertical, Bézier
    sampling (quadratic/cubic, de Casteljau), resample. Add pytest.ini
    (pythonpath=., cache disabled), requirements-dev.txt (pytest, ezdxf), and
    bootstrap_pytest.py (sandbox workaround: pip is blocked by the DSH sandbox
    tempfile denial, so pytest wheels are fetched directly). 25 tests green.
    Mark G2 done in the geometry-engine backlog.
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2026-08-24 feather: geometry engine G9 — markdown sync/lint
    Lint the §7 flight-feathers table of outline-templates.md against
    feathers.json (Total, Vane, Rachis out:in, Curve). Max width is skipped
    (explicitly superseded by the chord-ratio widths) and Tip is skipped
    (free-form doc wording). CLI via python -m feathergen.markdown_sync; 15
    tests green incl. drifted-row + missing-feather cases; mark G9 done —
    geometry engine complete.
2026-08-24 wiring: reorder JST-GH pinout (power outer pins, SDI/CLK mid) + swap power/GND
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2026-08-25 feather: soften geometry to match real-feather reference
    Curvature: drop bow fractions (high 8%->5%, med-high 6%->3.8%, med 4%->2.8%,
    med-low 2.5%->1.8%, low 1%->0.8%) so primaries read as gentle arcs, not
    banana curves (P4 lateral offset 1.43 cm).
    Tips: smaller cap radii (rounded-point .05->.04, rounded .10->.08,
    very-rounded .16->.12, hooked .08->.05) and a smaller hook (0.6/1.0 -> 0.45/0.8).
    Emargination: longer, shallower leading-edge taper (span 0.62-0.95 -> 0.55-0.96,
    depth 0.4 -> 0.3) instead of a small V-notch.
    Regenerate P4/S6 golden snapshots; fix emargination notch-point tests to
    identify inserted points against the original rail (not the inner rail).
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2026-08-25 Revert to off-the-shelf build: strip chunks, no custom PCBs
    Drop the custom strip-module PCB path (6-LED KiCad project, module designs,
    parts-local easyeda2kicad parts, EasyEDA script) and restore the COTS plan:
    SK9822 96 LED/m strips cut per feather, pigtail wiring, Pixelblaze + buck hubs.
    Update boards/README (source of truth), root README, connector pinout legend,
    feather lighting map, and mechanical wording to strip-chunk model.
    [wings-led-6.kicad_pcb, wings-led-6.kicad_sch]
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2026-08-25 boards: own all electrical info — lighting map, 96/m-only strip, COTS sourcing
    Move feather/lighting-and-boards.md into boards/ (LED map, chunk counts,
    power budget now sit with the electrical build) and commit the sourcing
    pass: 96 LED/m SK9822 only (no 144/m fallback) with vendor shortlist
    (Alibaba 96/m option, JAD-LEDS), Adafruit 74AHCT125 level shifter, MP1584EN
    buck modules, ATO fuse holders, JST-PH pigtail parts, silicone wire.
2026-08-25 feather: physical templating only — repo guidance + reference updates
    Add repository-level layout rules: feather/ carries mechanical feather
    templating only (outlines, geometry, generator, shape sourcing); all
    electronics information lives in boards/ (or docs/). Remove the lighting
    doc from feather/README, point every cross-reference at
    boards/lighting-and-boards.md, and fix stale feather paths in mechanical/.
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2026-08-25 boards: sync wiring docs to JST-PNI pigtails (wire-to-wire, crimp both ends)
    Replace the JST-PH 2-pin scheme: chunks carry PNI receptacles (PNIRR-02VF)
    on power-in/data-in/data-out; all jumpers and feeds are plugs (PNIRP-02V-S),
    both genders crimped, no soldered headers. Update the pinout legend (connector
    scheme, 20-22 AWG power / 24 AWG data, <=2-3 A per run) and rewrite the
    pigtail-crimping guide for the PN-family tooling.
2026-08-25 boards: parts list — switch connectors to JST-PNI (2-pin, wire-to-wire)
    PNI receptacle PNIRR-02VF + plug PNIRP-02V-S, socket SPND-001T-C0.5 +
    mating pin, PN-family crimp tool (SN-28B does not fit), pre-made pigtails
    (DigiKey pre-crimped leads, harness makers); wiring kept <=2-3 A per run.
2026-08-25 boards: correct PNI contact part numbers; drop pre-crimped-lead path
    PNI socket is SPNI-001T-P0.5 and pin is BPNI-001T-P0.5 (SPND-001T-C0.5 was
    the JST PN 3.96mm contact). Remove the pre-crimped lead option entirely
    (DigiKey ASPNISPNI family carries a 1000/color MOQ — unusable for a
    one-off); all pigtails are hand-crimped from loose contacts.
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2026-08-25 boards: MP1584EN-only hubs with honest rating (no heatsink)
    Fix the 3A-module claim: MP1584EN is rated 3A but practical ~2-2.5A at
    12V->5V with no heatsink. Size clusters to <=2A full-white (~5 feathers)
    per hub, drop the XL4015/LM2596 alternatives.
2026-08-25 boards: hub wiring — Wago push-in terminals + lever nuts, no screw terminals
    Hubs use spring-clamp (push-in) terminals on perfboard (Wago 2060-class)
    and Wago 221 lever nuts for 12V bus splices — vibration-proof, tool-less,
    lower profile. Add hub wiring flow + parts-list rows.
2026-08-25 feather: drop scaling tables + manifest; LS/MG derived from MD; sizing authority outside feather
    - source-images: delete scaling_tables.md/.json and manifest.csv; remove LS/MG
    crops (no sources — derive both rows from the MD archetype per §3.4c/§3.4d)
    - NAMING.md: replace per-feather tables with px:cm constants (peregrine 59.055,
    kestrel 236.22 px/cm), drop the manifest section + cross-check rules
    - outline-templates.md / PLAN.md / README: point scale steps at the px:cm
    constants; document LS/MG derivation; fix stale originals/ path
    - boards + mechanical: mark all feather sizing provisional — feather/ (not yet
    finalized) is the authoritative source
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2026-08-28 custom-electronics: FPC copper capped at 1oz — dual-layer rail sizing
    1oz (35um) is the max copper weight for flex; 2oz is not an option. Size
    VDD/GND rails for the buck-limited worst case (~3A) via 1.2mm traces +
    via-stitched dual-layer VDD instead of relying on heavier copper.
2026-08-28 custom-electronics: 5mm FPC width, confirmed JLCPCB constraints, 2-layer decision
    - Widen FPC to 5mm with SK9822-EC20 (2020, 1mm tall): fits feather budget at
    ~3mm angled; single 2.0mm VDD rail covers buck-limited worst case, no via stitching
    - Confirmed: flex copper capped at 1oz; min trace/space 4/4mil with +-0.2mm
    registration (drives mask-defined pads + conservative stencil plan)
    - Make 2-layer explicit with rationale (2020 pad routing, SPI ground pour)
    - Open items split into blocking (EC20 pinout, reel price) vs confirm-at-quote
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2026-08-28 custom-electronics: panelized board inventory (B7/B4/B3 subset)
    Assembly panel capped at 250x250mm -> max board 233mm (7 LEDs @ 33.3mm).
    Subset {B7, B4, B3} resolves feather counts with short chains; ~108 B7 +
    ~28 small boards across both wings in 4 panels; ~55 chain joints (feather
    lengths assumed, recheck before locking SKU mix).
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2026-08-28 wing-bones: feather scale x0.9085 (Atlas order P1=wing-tip), anatomical mounting fix, USFWS Feather Atlas renumbering
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2026-08-31 boards: fix hub-board deployment — rest group 10 taps (was 5), reconcile connectors with 17-tap injection map (4x12V terminals + 17x PH2.0-2PWB per wing)
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2026-08-31 led strip: correct EC20 decoupling — no internal cap; bulk 22uF 1206 (C12891, BASIC) per segment board, data under cap
2026-08-31 led strip: gen_schematic SKU set 7-12 + C1 bulk cap; project fp-lib-table (17 footprint libs) fixing footprint resolution; KiCad board/schematic updates from footprint remap
    [SK9822-EC20-strip.kicad_pcb, SK9822-EC20-strip.kicad_sch]
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2026-09-17 templates: as-built source images — add raw 20260917_091427, solo cardboard B5 re-shoot, S1-6 (replaces S1-5)
    - raw/20260917_091427.jpg: additional raw capture
    - unskewed/B5.jpg: B5 re-photographed on its own in cardboard; the original
    white-paper B5 was undetectable by find-template-outlines.py (same
    saturation as the printed sheet), so it is now a reliable detection
    - unskewed/S1-6.jpg: re-skew replaces S1-5.jpg
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2026-09-17 templates: outline labels — feather code only, no measurement
    - find-template-outlines.py: drop the length from both rendered labels
    - <stem>.svg <text>: "A1 16.2" -> "A1"
    - <stem>.overlay.png: "A1 16.2cm" -> "A1"
    - the code alone is short enough to sit above its template instead of
    sprawling across it, directly over the matching hand-written mark
    - dimensions are unaffected: still in templates-measured.csv
    (length_cm / width_cm / area_cm2 / aspect / position) and in the JSON
    - regenerated the 4 SVGs; all 42 label texts are now distinct feather codes
2026-09-17 templates: SVG outline = smoothed cubic Bezier, single black layer
    - add an error-bounded cubic Bezier fit of the unsimplified contour (Schneider,
    Graphics Gems 1990), fitted in physical units so the tolerance is isotropic
    - write_svg emits ONE black path group (id="outlines", stroke 0.5) with plain
    feather-code ids; the red comparison layer and the polyline layer are gone
    - --fit-mm (default 1.0 mm) is the smoothing lever; --no-smooth falls back to
    emitting the raw RDP polyline
    - --smooth-mm is deliberately NOT the lever: measured across all 42 templates at
    equal segment count, pre-smoothing 3-6 mm shortened feathers 1.5-4.0 mm by
    sawing the tip off, where the tolerance cost only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
2026-09-17 templates: individual feather SVGs — raster-free, one group, black flipped labels
    - strip the embedded background raster from all 42 files (3424 KB -> 49.6 KB)
    and drop xmlns:xlink once nothing references it
    - move each label from the crop corner to the pole of inaccessibility of its own
    outline: guaranteed inside and as far from the edge as the shape allows
    (verified 42/42 inside, min clearance 14.2 mm against 6 mm text)
    - label fill #d40000 -> #000, and rotated 180 deg about its own visual centre so
    the flipped glyphs occupy exactly the same box; rotating about the baseline
    would have shifted them by 0.7 em
    - collapse <g id="outlines"> + <g id="labels"> into one <g id="feather"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
2026-09-17 templates: aggregate feather catalog — one group per prefix, vertical flip
    build-feather-aggregate.py reads as-built/vectors/individuals/*.svg (the source
    of truth — the photo-detection tool is not involved) and writes one 1:1 mm
    catalog: <g id="catalog"> > <g id="P"> ... > <g id="P1"> > path + label.
    - Each individual file sits in its own photo sheet's mm frame, and the four
    sheets overlap in absolute coordinates (S1 lands on SC1), so feathers cannot
    just be concatenated: each is re-placed into a per-prefix row.
    - Placement and the mirror live on the feather's <g>; the <path> inside is
    copied verbatim (d and its own transform), so a group can be selected, moved
    or exported in a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
2026-09-17 templates: feather vectors — hand-arranged aggregate + top-lines guide
    The aggregate is no longer a generated catalog: it has been worked over in a
    vector editor into the wing arrangement, and it is the authority the individual
    files were split from. Every prefix group carries its own transform — S, A, PC,
    SC, MC and LC are rotated (SC +35 deg, MC -99 deg, LC -175 deg), P is scaled
    1.2001x in length and S/B about 1.2x — and 33 of the 42 feather groups carry a
    rotation of their own on top of that.
    top-lines.svg is a new 200x125 mm diagram in the same folder.
2026-09-17 templates: split the aggregate back into individual feather files
    split-feather-aggregate.py inverts build-feather-aggregate.py: it reads the
    authoritative aggregate and writes individuals/<LABEL>.svg per feather.
    - Files come out straightened — rotated so the minimum-area box's long side runs
    down the page with the tip at the bottom — at the size the aggregate gives
    them: the P group's 1.2001x length survives (P1 468.3 mm), the arrangement's
    rotation does not, and the shape is never re-fitted. PCA was tried first and
    left curved feathers a degree off; rotating calipers fixed that.
    - <g id="feather"> carries the composed transform (every ancestor times the
    feather group's own)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
2026-09-17 templates: separate the two halves of each mirrored pair
    The halves were butted together at the pair centre line, which made the
    templates unusable: the mirror-image cut outline sat directly against the edge
    being worked on. They are now held apart across the centre line.
    - 70 mm between the halves of a P or S pair (long primaries and secondaries)
    - 30 mm between the halves of every other pair
    Because a pair is now two half-widths plus its own gap, several groups no longer
    fit a second pair beside them, so the document grows to 16 pages:
    - pair width now includes the half-to-half gap, so every fit check sees it once
    - page side margins shrink from 12 mm to as little as 5 mm when a wide pa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
2026-09-17 templates: drop the LEFT/RIGHT side captions
    The half labels "LEFT - mirror" and "RIGHT - as built" are redundant now that
    the ID labels carry a side suffix (`P1 L` / `P1 R`). Removing them also takes a
    line out of the per-pair label band, so pages are a little shorter.
    - slot_labels now returns the two ID labels only
    - the render and pypdf verifiers check the ID labels instead, and the pypdf
    verifier fails if either side caption reappears
2026-09-17 templates: accept the internal SC4 flip, regenerate print PDF
    SC4.svg was re-normalised: the group transform's reflection moved into the path
    data, flipping the shape 180 degrees in place. Its overall size is unchanged
    (56.064 x 161.690 mm, matching the declared page), so no layout or page size is
    affected - only SC4's own outline on page 12.
    Regenerates print/feathers-mirrored-pairs.pdf, which was still the pre-change
    artifact: it now carries the corrected SC4 outline and the label change from the
    previous commit (the LEFT/RIGHT side captions are gone; the ID labels' L/R
    suffix carries the side).
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2026-09-18 templates: 200 mm document, rotating the tall small-feather pairs
    Adds a second generated document for printers that only take short sheets.
    Every page is 200 mm or less tall, while P, S and B keep the larger pages
    they need.
    To fit, the SC, PC and A pairs are laid down rotated 90 degrees clockwise, so
    the feather's long axis runs across the page. Rotation swaps a pair's extents
    (169.7 x 145.5 mm becomes 145.5 x 169.7 mm), which is what gets them under the
    cap: they are too tall as single pairs for any amount of spacing to rescue.
    - new --rotate FAMILY ... option; the default rotates nothing, so the existing
    16-page document is byte-identical to before
    - PairSlot gains `rotated` and `axi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
2026-09-22 tools: printable mirrored-pair PDF straight from the feather aggregate
    The per-feather generator could not run any more: it reads one SVG per feather
    from as-built/vectors/individuals/, and those files were deleted. This adds a
    self-contained replacement that takes its paths straight out of
    as-built/vectors/feathers-aggregate.svg and writes a new 15-page document,
    as-built/print/feathers-from-aggregate.pdf, holding all 42 feathers as
    left/right mirrored pairs at 1:1.
    Three things the aggregate needs that the per-file source did not:
    - the `toplines` group is scaffolding, not cut lines, so it is never entered
    (nor is any other group hidden by its style);
    - centre lines are read, because t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
2026-09-24 templates: split the small feathers onto short pages, precalculate the sheets
    The aggregate generator packed every family to the same 1050 mm budget, so a
    small covert shared a 1036 mm page with four of its neighbours and needed six
    sheets to print. The small coverts are now held to their own page height
    (--small-page-height, 200 mm), the way the old 200 mm document did it: SC, PC,
    A, MC and LC pages come out 135-194 mm, which is one row of sheets instead of a
    grid. P, S and B keep the full budget -- a single pair of theirs is 405-567 mm
    tall and no budget would change that.
    before: 15 pages, 405-1044 mm, the small groups on 1036/1044/977/739 mm
    after: 31 pages, 135-837 mm, 20 of t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
2026-09-24 tiling: start the page width from the paper, so 8.5x11 tiles one column too
    The settled page width started from a flat 273 mm whatever the paper was. Against
    an 8.5x11 sheet (269.4 mm of printable width) that is already too wide, so the
    page widened to fit its pair and then needed two columns -- which hid the fact
    that the pair would have fitted one column at a slightly smaller gap.
    The nominal width now depends on the build: an explicit --page-width wins,
    otherwise a tiled build starts from the paper's printable width and a poster
    build from the 273 mm default. nominal_page_width() holds that rule, the
    generator and the verifier both use it.
    With the source's P1 narrowed to 98.7 mm across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
2026-09-24 templates: regenerate the print PDF with the small feathers back
    The smaller coverts were hidden in the source (display:none on the PC, A, S, SC,
    MC and LC groups), which is why they were absent: the generator skips a hidden
    group by design, so the document had 8 of the 28 feather groups the file holds.
    They are visible again, and all 28 reach the paper.
    20 logical pages -> 43 A4 landscape sheets
    7 long pages tiled down a single column (30 sheets)
    13 small-feather pages printed whole on one sheet each
    8.5x11 gives 43 sheets too, at 21 logical pages (the narrower page fits one fewer
    pair per page).
    Checked: every one of the 28 feather IDs appears in the document's text layer,
    a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
2026-09-24 toplines: draw the leading-edge guides, one sheet per side
    --toplines draws the group instead of the templates: two pages, the right side as
    the aggregate holds it and its mirror for the left. The group is still skipped
    when reading feathers -- it is not a cut line -- so nothing about the template
    documents changes.
    The drawing is 182 x 96 mm in the aggregate's frame, well inside both papers
    (A4 landscape prints 287 x 200 mm, 8.5x11 prints 269.4 x 205.9), so it prints at
    TRUE SIZE by default and is only ever reduced to fit, never enlarged: it is a size
    reference as much as a picture, and 1:1 lets it be laid over the templates it
    describes. The scale goes on the page under the title.
    The le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
2026-09-24 templates: integrate the visibility lines into the aggregate source
    --integrate writes the computed visibility lines back into the aggregate SVG. The
    lines are computed in absolute mm, but every feather in the source sits in its own
    transformed frame, so each polyline is mapped back through the inverse of its
    feather group's composed transform and inserted as a <path class="visibility-line">
    right after that feather's outline -- inside the group, where it inherits the same
    transform. A .visibility-line rule goes into the stylesheet.
    Re-running replaces the paths it wrote before rather than stacking them, so the
    source stays clean.
    Checked against the current source: 27 paths (LC3 is fully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
2026-09-24 templates: renumber the secondary coverts SC1-SC4
    The SC row skipped a number (SC1, SC3, SC4, SC5), so the ids did not read as
    1..4. Closed the gap: SC3->SC2, SC4->SC3, SC5->SC4, across the group ids, the
    outline/label/visibility-line ids and the printed label text.
    Nothing moves -- the order is unchanged, so the stacking and the visibility
    lines are the same geometry under new names.
    Both print PDFs rebuilt so the labels they carry match.
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2026-09-25 docs: record B-group rotation correction in print plan
    B1-B3 are stored horizontal (long axis across) and must be rotated 90 deg
    clockwise before pairing. This flips their pair geometry from wide (2-column
    tiles) to tall (1-column: B1 now fits whole, B2/B3 tile 1x2).
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2026-09-25 docs: record implementation decisions and verification results
    - cairosvg inflates explicit CSS units ~3.78x; all stroke-width/font-size
    are therefore unitless (user units = mm).
    - scale tolerance relaxed to +-1 mm (ink extent includes the 0.5 mm stroke).
    - B rotation verified (tall pair, exact mirror).
    - script kept committed and tweakable; scratch gitignored, PDF tracked.
    - verification: 29 pages, 28/28 labels, mirror exact, bars 100.4/102.0 mm.
2026-09-26 add placement + alignment templates (left/right) to print output
    Generalise the pair builder to an Item (name, W, H, body, inside_label), so the
    same mirror + tile + pack pipeline prints feathers and guide templates alike.
    New items, after the 28 feathers:
    - outline-toplines.svg (whole-wing placement template). Its external <use>
    references are expanded inline (cairosvg renders them blank), then the item
    is cropped to the measured ink bbox (~249x257 mm) instead of the loose
    300x300 canvas, so it tiles 2x2 instead of wasting sheets.
    - A/B/LC/MC/P/PC/S/SC-topline.svg (per-family alignment guides). Their paths
    carry a matrix transform (kept verbatim) and a px stroke (normalised to the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
